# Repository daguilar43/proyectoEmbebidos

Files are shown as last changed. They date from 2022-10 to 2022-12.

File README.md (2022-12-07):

# Proyecto Sistemas Embebidos
#

Aquí pueden encontrarse todos los archivos del proyecto Amiplanta realizado para la materia Sistemas Embebidos durante el semestre 2022-2 en la Universidad Nacional de Colombia.
Dentro de estas carpetas pueden encontrarse:

*Proyecto en Kicad con el esquemático del dispositivo, huellas de los los diferentes componentes y layout de la PCB que fue enviada a producción con sus 
respectivas reglas de diseño + Logo del proyecto en la máscara de la PCB.

*Huellas realizadas manualmente de alunos componentes (utilizados para el diseño de la PCB).

*Código final desarrollado con ayuda de RIOT OS y el sdk para la Esp32-Wroom32, placa que fue utilizada para el montaje del proyecto.

*Modelo 3D utilizado para la matera.

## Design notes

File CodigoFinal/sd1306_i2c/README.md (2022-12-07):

#Código main.c

Este código utiliza las funciones de lectura y escritura definidas en los archivos de periféricos.
Además, se basa en el código ejemplo U8g2 para escribir y mostrar gráficos en una oled 128x64px.

Primero se realizar la inicialización de cada uno de los sensores. Posteriormente se realiza la inicialización de la pantalla.

Finalmente, se calculan las emociones a partir de medidas en cada uno de los sensores y se imprime en pantalla la emoción calculada.

Se cuenta con 5 emociones:

  *Feliz (todos los sensores en los rangos establecidos
  *Ahogado (demasiada humedad)
  *Sediento (humedad demasiado baja)
  *Oscuridad (baja luminosidad)
  *Frio (Temperatura baja)
  *Calor (Temperatura alta)

# U8g2 Package Test

## About
This is a test application for the U8g2 package. This package is a graphical display library, including display drivers.

## Usage
This test application will initialize the U8g2 to output on one of the following:

* output to terminal virtual screen.
* output to SDL virtual screen.
* output to I2C graphics screen.
* output to SPI graphics screen.

Note: you may have to run `make clean` after you changed to a different output mode.

### Output to terminal
To output to this virtual screen, supply `TEST_OUTPUT=1` to the `make` command.

### Output to SDL
To output to this virtual screen, supply `TEST_OUTPUT=2` to the `make` command.

This is a native-only option and requires SDL (32-bits) to be installed.

### Output to SPI
To output to screen, supply `TEST_OUTPUT=3` to the `make` command.

* `TEST_SPI` &mdash; The SPI device.
* `TEST_PIN_CS` &mdash; If applicable, the CS pin.
* `TEST_PIN_DC` &mdash; If applicable, the Data/Command pin.
* `TEST_PIN_RESET` &mdash; If applicable, the reset pin.
* `TEST_DISPLAY` &mdash; The used display driver (see https://github.com/olikraus/u8g2/wiki/u8g2setupc). Make sure you select a SPI compatible display.

### Output to I2C
To output to screen, supply `TEST_OUTPUT=4` to the `make` command.

Furthermore, you can configure the following:

* `TEST_I2C` &mdash; The I2C device.
* `TEST_ADDR` &mdash; The address to write commands to.
* `TEST_PIN_RESET` &mdash; If applicable, the reset pin.
* `TEST_DISPLAY` &mdash; The used display driver (see https://github.com/olikraus/u8g2/wiki/u8g2setupc). Make sure you select an I2C compatible display.

## Expected result
The output of this test depends on the output mode and used hardware. If it works, the application cycles through three screens with the text: 'This is RIOT-OS'.

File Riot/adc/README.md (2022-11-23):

ADC
===

Instrucciones de construcción
=============================

Acivar variables de entorno:

```bash
. environment.bash
```

Construir, flashear y monitorear:

```bash
    make b f t
```
Revisión de la documentación para modificaciones
================================================

https://doc.riot-os.org/group__drivers__periph__adc.html

ADC_NUMOF

/home/johnny/gitPackages/RIOT/boards/esp32-wroom-32/include/periph_conf.h
```bash
// ADC_GPIOS wroover
#define ADC_GPIOS   { GPIO0 , GPIO2 , GPIO4 , GPIO12, GPIO13, GPIO14, \
                      GPIO15, GPIO25, GPIO26, GPIO27, GPIO32, GPIO33, \
                      GPIO34, GPIO35, GPIO36, GPIO39 }
```

ADC_LINE(x)
Donde x es la posición que ocupa el pin en el arreglo de ADC_GPIOS

```bash
#define ADC_GPIOS {GPIO0, ..., GPIO39}
GPIO0 -> 0
GPIO2
GPIO4
GPIO12
GPIO13
GPIO14
GPIO15
GPIO25 -> 7
GPIO26
GPIO27
GPIO32
GPIO33
GPIO34
GPIO35
GPIO36
GPIO39 -> 15
```

/home/johnny/gitPackages/RIOT/boards/common/esp32/include/periph_conf_common.h

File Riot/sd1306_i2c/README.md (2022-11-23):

# U8g2 Package Test

## About
This is a test application for the U8g2 package. This package is a graphical display library, including display drivers.

## Usage
This test application will initialize the U8g2 to output on one of the following:

* output to terminal virtual screen.
* output to SDL virtual screen.
* output to I2C graphics screen.
* output to SPI graphics screen.

Note: you may have to run `make clean` after you changed to a different output mode.

### Output to terminal
To output to this virtual screen, supply `TEST_OUTPUT=1` to the `make` command.

### Output to SDL
To output to this virtual screen, supply `TEST_OUTPUT=2` to the `make` command.

This is a native-only option and requires SDL (32-bits) to be installed.

### Output to SPI
To output to screen, supply `TEST_OUTPUT=3` to the `make` command.

* `TEST_SPI` &mdash; The SPI device.
* `TEST_PIN_CS` &mdash; If applicable, the CS pin.
* `TEST_PIN_DC` &mdash; If applicable, the Data/Command pin.
* `TEST_PIN_RESET` &mdash; If applicable, the reset pin.
* `TEST_DISPLAY` &mdash; The used display driver (see https://github.com/olikraus/u8g2/wiki/u8g2setupc). Make sure you select a SPI compatible display.

### Output to I2C
To output to screen, supply `TEST_OUTPUT=4` to the `make` command.

Furthermore, you can configure the following:

* `TEST_I2C` &mdash; The I2C device.
* `TEST_ADDR` &mdash; The address to write commands to.
* `TEST_PIN_RESET` &mdash; If applicable, the reset pin.
* `TEST_DISPLAY` &mdash; The used display driver (see https://github.com/olikraus/u8g2/wiki/u8g2setupc). Make sure you select an I2C compatible display.

## Expected result
The output of this test depends on the output mode and used hardware. If it works, the application cycles through three screens with the text: 'This is RIOT-OS'.

##Imagen personalizada
Se debe preescalar la imagen deseada a 128*64px. Posteriormente utilizar la siguiente herramienta: https://javl.github.io/image2cpp/ para generar el mapa de bits en 128*64px

##Ruta del Riot
Modificar la variable RIOTBASE en archivo makefile y .envioroment para que corresponda con el directorio en el que se intaló RIOT.

##Ejecución

Ejecutar en consola:
*. environment.bash
*make all flash terminal

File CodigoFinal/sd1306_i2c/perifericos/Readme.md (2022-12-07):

Estos archivos contienen las funciones básicas para el funcionamiento de la Amiplanta.

El archivo adc.c contiene la lógica para la inicialización y lectura de cada uno de los sensores excepto el sensor de luz.
Estos sensores en general son adcs y gpios.

El archivo sensorLuz.c contiene la lógica para inicializar y controlar el sensor de luz utilizado. Este utiliza funciones base de i2c, lo que permite calibrar la 
resolución necesaria y prender el dispositivo para tomar lecturas.

El archivo carasOled.c contiene los mapas de bit de cada una de las emociones utilizadas por el programa. Además maneja la pantalla escribiendo los mapas de bits y 
calcula las emociones en funcion de la lectura de los diferentes sensores.

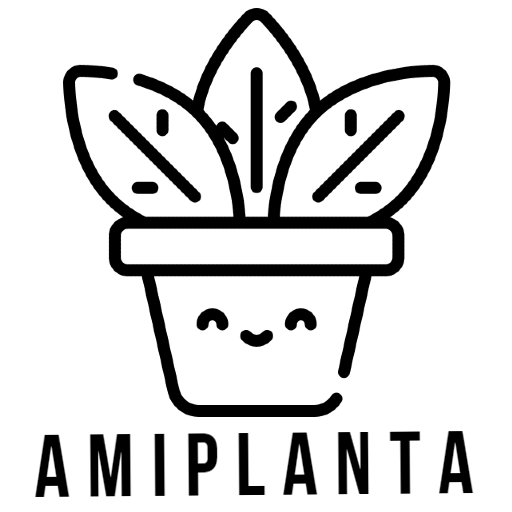
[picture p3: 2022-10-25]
Amiplanta.png

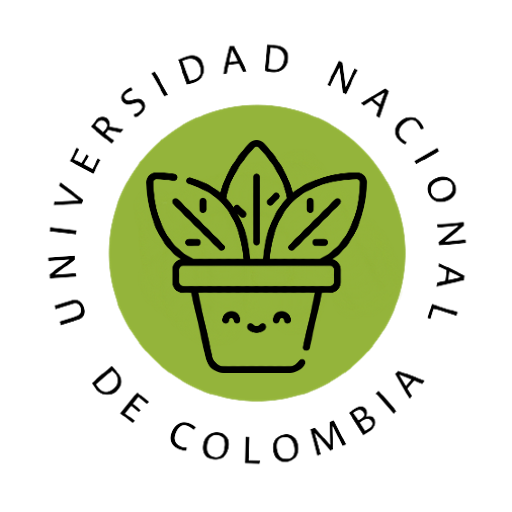
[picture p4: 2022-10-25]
EsquematicoV4/planta.png

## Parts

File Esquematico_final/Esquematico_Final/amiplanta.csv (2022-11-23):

Source: | /proyectoEmbebidos/proyectoEmbebidos/Esquematico_final/Esquematico_Final/amiplanta.kicad_sch
Date: | Tue 01 Nov 2022 10:18:04 AM -05
Tool: | Eeschema 6.0.9-8da3e8f707~116~ubuntu20.04.1
Generator: | /usr/share/kicad/plugins/bom_csv_grouped_by_value.py
Component Count: | 48
Individual Components:
Item | Qty | Reference(s) | Value | LibPart | Footprint | Datasheet | DESCRIPTION | MANUFACTURER | MAXIMUM_PACKAGE_HEIGHT | MP | PACKAGE | PARTREV | PRICE | STANDARD
 |  | Camp1 | 10u | Device:C | Capacitor_SMD:C_0805_2012Metric_Pad1.18x1.45mm_HandSolder | ~
 |  | Camp2 | 0.1u | Device:C | Capacitor_SMD:C_0805_2012Metric_Pad1.18x1.45mm_HandSolder | ~
 |  | Cbl1 | 0.1uF/50V(10%) | Device:C | Capacitor_SMD:C_0805_2012Metric_Pad1.18x1.45mm_HandSolder | ~
 |  | Cbl2 | 4.7uF/6.3V(10%) | Device:C | Capacitor_SMD:C_0805_2012Metric_Pad1.18x1.45mm_HandSolder | ~
 |  | Cboot1 | 0.1uF/50V(10%)(NC) | Device:C | Capacitor_SMD:C_0805_2012Metric_Pad1.18x1.45mm_HandSolder | ~
 |  | Cen2 | 0.1uF/50V(10%)(NC) | Device:C | Capacitor_SMD:C_0805_2012Metric_Pad1.18x1.45mm_HandSolder | ~
 |  | Cfeed1 | 22uF/10V(20%) | Device:C | Capacitor_SMD:C_0805_2012Metric_Pad1.18x1.45mm_HandSolder | ~
 |  | Cfeed2 | 0.1uF/50(10%) | Device:C | Capacitor_SMD:C_0805_2012Metric_Pad1.18x1.45mm_HandSolder | ~
 |  | CReg1 | 1u | Device:C | Capacitor_SMD:C_0805_2012Metric_Pad1.18x1.45mm_HandSolder | ~
 |  | CReg2 | 1u | Device:C | Capacitor_SMD:C_0805_2012Metric_Pad1.18x1.45mm_HandSolder | ~
 |  | Din1 | MBR1020VL | Diode:MBR1020VL | Diode_SMD:D_SOD-123F | https://www.onsemi.com/pub/Collateral/MBR1020VL-D.PDF
 |  | Dinl1 | LESD5D5.0CT1G | LESD5D5.0CT1G:LESD5D5.0CT1G | LESD5D5:TVS_LESD5D5.0CT1G |  |  | LRC | 0.7 mm |  |  | O |  | Manufacturer Recommendations
 |  | DUl1 | LESD5D5.0CT1G | LESD5D5.0CT1G:LESD5D5.0CT1G | LESD5D5:TVS_LESD5D5.0CT1G |  |  | LRC | 0.7 mm |  |  | O |  | Manufacturer Recommendations
 |  | DUl2 | LESD5D5.0CT1G | LESD5D5.0CT1G:LESD5D5.0CT1G | LESD5D5:TVS_LESD5D5.0CT1G |  |  | LRC | 0.7 mm |  |  | O |  | Manufacturer Recommendations
 |  | DUl3 | LESD5D5.0CT1G | LESD5D5.0CT1G:LESD5D5.0CT1G | LESD5D5:TVS_LESD5D5.0CT1G |  |  | LRC | 0.7 mm |  |  | O |  | Manufacturer Recommendations
 |  | DUSB1 | BAT760-7 | BAT760-7:BAT760-7 | SOD2513X120N |  |  | DIODES | 1.20mm |  |  | 9-2 |  | IPC-7351B
 |  | J1 | Jack-DC | Connector:Jack-DC | Connector_BarrelJack:BarrelJack_Horizontal | ~
 |  | J2 | USB_B_Micro | Connector:USB_B_Micro | Connector_USB:USB_Micro-B_Wuerth_629105150521 | ~
 |  | J3 | Conn_01x03_Female | Connector:Conn_01x03_Female | Connector_PinHeader_2.54mm:PinHeader_1x03_P2.54mm_Vertical | ~
 |  | Jhum1 | Conn_01x03_Female | Connector:Conn_01x03_Female | Connector_Molex:Molex_KK-396_A-41791-0003_1x03_P3.96mm_Vertical | ~
 |  | Jluc1 | Conn_01x06_Female | Connector:Conn_01x06_Female | Connector_Molex:Molex_KK-396_A-41791-0006_1x06_P3.96mm_Vertical | ~
 |  | Jmov1 | Conn_01x03_Female | Connector:Conn_01x03_Female | Connector_Molex:Molex_KK-396_A-41791-0003_1x03_P3.96mm_Vertical | ~
 |  | Joled1 | Conn_01x04_Female | Connector:Conn_01x04_Female | Connector_Molex:Molex_KK-396_5273-04A_1x04_P3.96mm_Vertical | ~
 |  | Jtem1 | Conn_01x03_Female | Connector:Conn_01x03_Female | Connector_Molex:Molex_KK-396_A-41791-0003_1x03_P3.96mm_Vertical | ~
 |  | Q1 | SS8050-G | SS8050-G:SS8050-G | SS8050-G:TRANS_SS8050-G |  |  | Comchip | 1.05 mm |  |  | A |  | Manufacturer Recommendations
 |  | Q2 | SS8050-G | SS8050-G:SS8050-G | SS8050-G:TRANS_SS8050-G |  |  | Comchip | 1.05 mm |  |  | A |  | Manufacturer Recommendations
 |  | R_rstbl1 | 2k(5%) | Device:R | Resistor_SMD:R_0805_2012Metric_Pad1.20x1.40mm_HandSolder | ~
 |  | Ractbl1 | 10k(5%) | Device:R | Resistor_SMD:R_0805_2012Metric_Pad1.20x1.40mm_HandSolder | ~
 |  | Rboot1 | 10K(5%) | Device:R | Resistor_SMD:R_0805_2012Metric_Pad1.20x1.40mm_HandSolder | ~
 |  | RDTR1 | 10K(5%) | Device:R | Resistor_SMD:R_0805_2012Metric_Pad1.20x1.40mm_HandSolder | ~
 |  | RED1 | LED | Device:LED | Resistor_SMD:R_0805_2012Metric_Pad1.20x1.40mm_HandSolder | ~
 |  | Ren1 | 10K(5%) | Device:R | Resistor_SMD:R_0805_2012Metric_Pad1.20x1.40mm_HandSolder | ~
 |  | Rpw1 | 1k | Device:R | Resistor_SMD:R_0805_2012Metric_Pad1.20x1.40mm_HandSolder | ~
 |  | RRTS1 | 10K(5%) | Device:R | Resistor_SMD:R_0805_2012Metric_Pad1.20x1.40mm_HandSolder | ~
 |  | RRXD0 | 0R(5%) | Device:R | Resistor_SMD:R_0805_2012Metric_Pad1.20x1.40mm_HandSolder | ~
 |  | rscl1 | 4.7k | Device:R | Resistor_SMD:R_0805_2012Metric_Pad1.20x1.40mm_HandSolder | ~
 |  | rsda1 | 4.7k | Device:R | Resistor_SMD:R_0805_2012Metric_Pad1.20x1.40mm_HandSolder | ~
 |  | Rtemp1 | 4,7k | Device:R | Resistor_SMD:R_0805_2012Metric_Pad1.20x1.40mm_HandSolder | ~
 |  | RTXD0 | 0R(5%) | Device:R | Resistor_SMD:R_0805_2012Metric_Pad1.20x1.40mm_HandSolder | ~
 |  | Rvbus1 | 22.1K(5%) | Device:R | Resistor_SMD:R_0805_2012Metric_Pad1.20x1.40mm_HandSolder | ~
 |  | Rvbus2 | 47.5K(5%) | Device:R | Resistor_SMD:R_0805_2012Metric_Pad1.20x1.40mm_HandSolder | ~
 |  | SWBoot1 | SW_Push | Switch:SW_Push | Button_Switch_SMD:SW_Push_1P1T_NO_6x6mm_H9.5mm | ~
 |  | SWEnable1 | SW_Push | Switch:SW_Push | Button_Switch_SMD:SW_Push_1P1T_NO_6x6mm_H9.5mm | ~
 |  | SWin1 | SW_DIP_x01 | Switch:SW_DIP_x01 | Button_Switch_SMD:SW_DIP_SPSTx01_Slide_9.78x4.72mm_W8.61mm_P2.54mm | ~
 |  | U2 | MAX98357AETE+ | MAX98357AETE_:MAX98357AETE+ | MAX9835_EditadoLib:MAX98357A_ModuloEditado | https://datasheets.maximintegrated.com/en/ds/MAX98357A-MAX98357B.pdf | Audio Amp Speaker 1-CH Mono Class-D 16-Pin TQFN EP | Maxim Integrated |  | MAX98357AETE+ | TQFN-16 Maxim Integrated |  | None | IPC7351B
 |  | U3 | ESP32-WROOM-32 | RF_Module:ESP32-WROOM-32 | RF_Module:ESP32-WROOM-32 | https://www.espressif.com/sites/default/files/documentation/esp32-wroom-32_datasheet_en.pdf
 |  | U7 | CP2102N-Axx-xQFN28 | Interface_USB:CP2102N-Axx-xQFN28 | Package_DFN_QFN:QFN-28-1EP_5x5mm_P0.5mm_EP3.35x3.35mm | https://www.silabs.com/documents/public/data-sheets/cp2102n-datasheet.pdf
 |  | UReg1 | AMS1117-3.3 | Regulator_Linear:AMS1117-3.3 | Package_TO_SOT_SMD:SOT-223-3_TabPin2 | http://www.advanced-monolithic.com/pdf/ds1117.pdf
Collated Components:
Item | Qty | Reference(s) | Value | LibPart | Footprint | Datasheet | DESCRIPTION | MANUFACTURER | MAXIMUM_PACKAGE_HEIGHT | MP | PACKAGE | PARTREV | PRICE | STANDARD
1 | 1 | Camp1 | 10u | Device:C | Capacitor_SMD:C_0805_2012Metric_Pad1.18x1.45mm_HandSolder | ~
2 | 1 | Camp2 | 0.1u | Device:C | Capacitor_SMD:C_0805_2012Metric_Pad1.18x1.45mm_HandSolder | ~
3 | 1 | Cbl1 | 0.1uF/50V(10%) | Device:C | Capacitor_SMD:C_0805_2012Metric_Pad1.18x1.45mm_HandSolder | ~
4 | 1 | Cbl2 | 4.7uF/6.3V(10%) | Device:C | Capacitor_SMD:C_0805_2012Metric_Pad1.18x1.45mm_HandSolder | ~
5 | 2 | Cboot1, Cen2 | 0.1uF/50V(10%)(NC) | Device:C | Capacitor_SMD:C_0805_2012Metric_Pad1.18x1.45mm_HandSolder | ~
6 | 1 | Cfeed1 | 22uF/10V(20%) | Device:C | Capacitor_SMD:C_0805_2012Metric_Pad1.18x1.45mm_HandSolder | ~
7 | 1 | Cfeed2 | 0.1uF/50(10%) | Device:C | Capacitor_SMD:C_0805_2012Metric_Pad1.18x1.45mm_HandSolder | ~
8 | 2 | CReg1, CReg2 | 1u | Device:C | Capacitor_SMD:C_0805_2012Metric_Pad1.18x1.45mm_HandSolder | ~
9 | 1 | Din1 | MBR1020VL | Diode:MBR1020VL | Diode_SMD:D_SOD-123F | https://www.onsemi.com/pub/Collateral/MBR1020VL-D.PDF
10 | 4 | Dinl1, DUl1, DUl2, DUl3 | LESD5D5.0CT1G | LESD5D5.0CT1G:LESD5D5.0CT1G | LESD5D5:TVS_LESD5D5.0CT1G |  |  | LRC | 0.7 mm |  |  | O |  | Manufacturer Recommendations
11 | 1 | DUSB1 | BAT760-7 | BAT760-7:BAT760-7 | SOD2513X120N |  |  | DIODES | 1.20mm |  |  | 9-2 |  | IPC-7351B
12 | 1 | J1 | Jack-DC | Connector:Jack-DC | Connector_BarrelJack:BarrelJack_Horizontal | ~
13 | 1 | J2 | USB_B_Micro | Connector:USB_B_Micro | Connector_USB:USB_Micro-B_Wuerth_629105150521 | ~
14 | 1 | J3 | Conn_01x03_Female | Connector:Conn_01x03_Female | Connector_PinHeader_2.54mm:PinHeader_1x03_P2.54mm_Vertical | ~
15 | 3 | Jhum1, Jmov1, Jtem1 | Conn_01x03_Female | Connector:Conn_01x03_Female | Connector_Molex:Molex_KK-396_A-41791-0003_1x03_P3.96mm_Vertical | ~
16 | 1 | Jluc1 | Conn_01x06_Female | Connector:Conn_01x06_Female | Connector_Molex:Molex_KK-396_A-41791-0006_1x06_P3.96mm_Vertical | ~
17 | 1 | Joled1 | Conn_01x04_Female | Connector:Conn_01x04_Female | Connector_Molex:Molex_KK-396_5273-04A_1x04_P3.96mm_Vertical | ~
18 | 2 | Q1, Q2 | SS8050-G | SS8050-G:SS8050-G | SS8050-G:TRANS_SS8050-G |  |  | Comchip | 1.05 mm |  |  | A |  | Manufacturer Recommendations
19 | 1 | R_rstbl1 | 2k(5%) | Device:R | Resistor_SMD:R_0805_2012Metric_Pad1.20x1.40mm_HandSolder | ~
20 | 1 | Ractbl1 | 10k(5%) | Device:R | Resistor_SMD:R_0805_2012Metric_Pad1.20x1.40mm_HandSolder | ~
21 | 4 | Rboot1, RDTR1, Ren1, RRTS1 | 10K(5%) | Device:R | Resistor_SMD:R_0805_2012Metric_Pad1.20x1.40mm_HandSolder | ~
22 | 1 | RED1 | LED | Device:LED | Resistor_SMD:R_0805_2012Metric_Pad1.20x1.40mm_HandSolder | ~
23 | 1 | Rpw1 | 1k | Device:R | Resistor_SMD:R_0805_2012Metric_Pad1.20x1.40mm_HandSolder | ~
24 | 2 | RRXD0, RTXD0 | 0R(5%) | Device:R | Resistor_SMD:R_0805_2012Metric_Pad1.20x1.40mm_HandSolder | ~
25 | 2 | rscl1, rsda1 | 4.7k | Device:R | Resistor_SMD:R_0805_2012Metric_Pad1.20x1.40mm_HandSolder | ~
26 | 1 | Rtemp1 | 4,7k | Device:R | Resistor_SMD:R_0805_2012Metric_Pad1.20x1.40mm_HandSolder | ~
27 | 1 | Rvbus1 | 22.1K(5%) | Device:R | Resistor_SMD:R_0805_2012Metric_Pad1.20x1.40mm_HandSolder | ~
28 | 1 | Rvbus2 | 47.5K(5%) | Device:R | Resistor_SMD:R_0805_2012Metric_Pad1.20x1.40mm_HandSolder | ~
29 | 2 | SWBoot1, SWEnable1 | SW_Push | Switch:SW_Push | Button_Switch_SMD:SW_Push_1P1T_NO_6x6mm_H9.5mm | ~
30 | 1 | SWin1 | SW_DIP_x01 | Switch:SW_DIP_x01 | Button_Switch_SMD:SW_DIP_SPSTx01_Slide_9.78x4.72mm_W8.61mm_P2.54mm | ~
31 | 1 | U2 | MAX98357AETE+ | MAX98357AETE_:MAX98357AETE+ | MAX9835_EditadoLib:MAX98357A_ModuloEditado | https://datasheets.maximintegrated.com/en/ds/MAX98357A-MAX98357B.pdf | Audio Amp Speaker 1-CH Mono Class-D 16-Pin TQFN EP | Maxim Integrated |  | MAX98357AETE+ | TQFN-16 Maxim Integrated |  | None | IPC7351B
32 | 1 | U3 | ESP32-WROOM-32 | RF_Module:ESP32-WROOM-32 | RF_Module:ESP32-WROOM-32 | https://www.espressif.com/sites/default/files/documentation/esp32-wroom-32_datasheet_en.pdf
33 | 1 | U7 | CP2102N-Axx-xQFN28 | Interface_USB:CP2102N-Axx-xQFN28 | Package_DFN_QFN:QFN-28-1EP_5x5mm_P0.5mm_EP3.35x3.35mm | https://www.silabs.com/documents/public/data-sheets/cp2102n-datasheet.pdf
34 | 1 | UReg1 | AMS1117-3.3 | Regulator_Linear:AMS1117-3.3 | Package_TO_SOT_SMD:SOT-223-3_TabPin2 | http://www.advanced-monolithic.com/pdf/ds1117.pdf

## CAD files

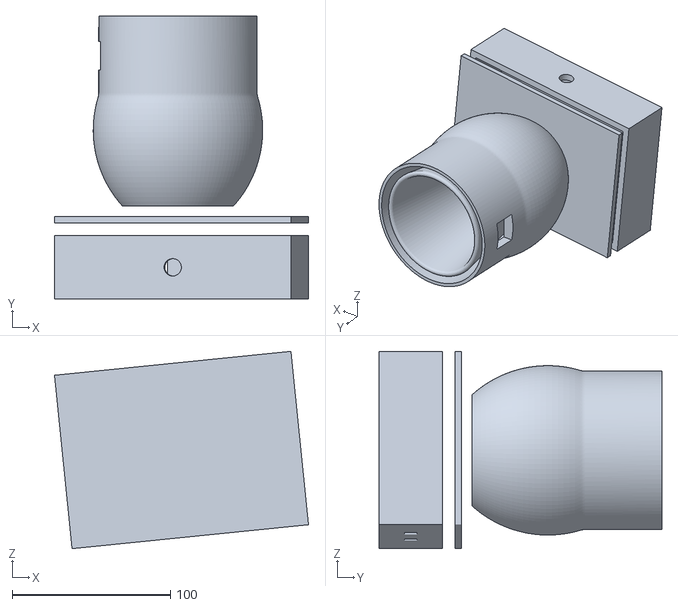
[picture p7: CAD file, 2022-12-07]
ensamble v11.stl
160.3 x 178.6 x 124.6

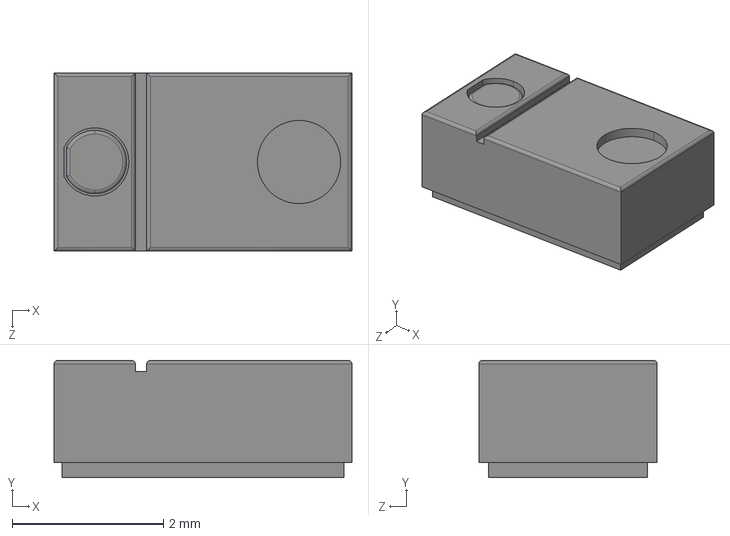
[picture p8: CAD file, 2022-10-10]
Esquematico_final/Esquematico_Final/Componentes/APDS-9960/APDS-9960.step
3.94 x 1.55 x 2.36 mm

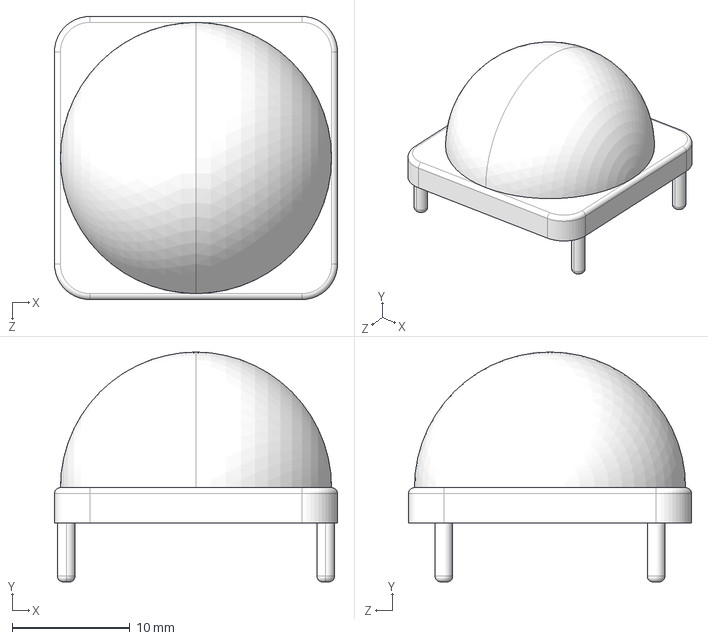
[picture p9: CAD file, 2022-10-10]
Esquematico_final/Esquematico_Final/Componentes/HC-SR501/HC-SR501-master/lens.STEP
24.0 x 19.5 x 24.0 mm

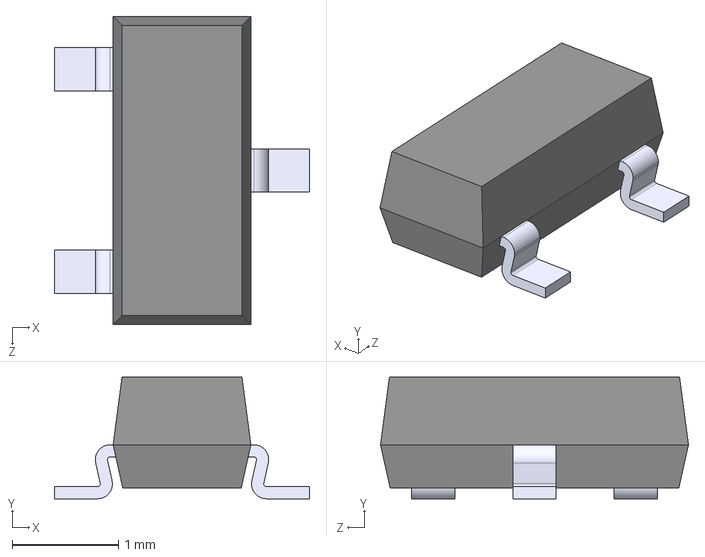
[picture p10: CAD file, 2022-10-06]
Esquematico_final/Esquematico_Final/Componentes/SS8050-G/SS8050-G.step
2.40 x 1.14 x 2.90 mm

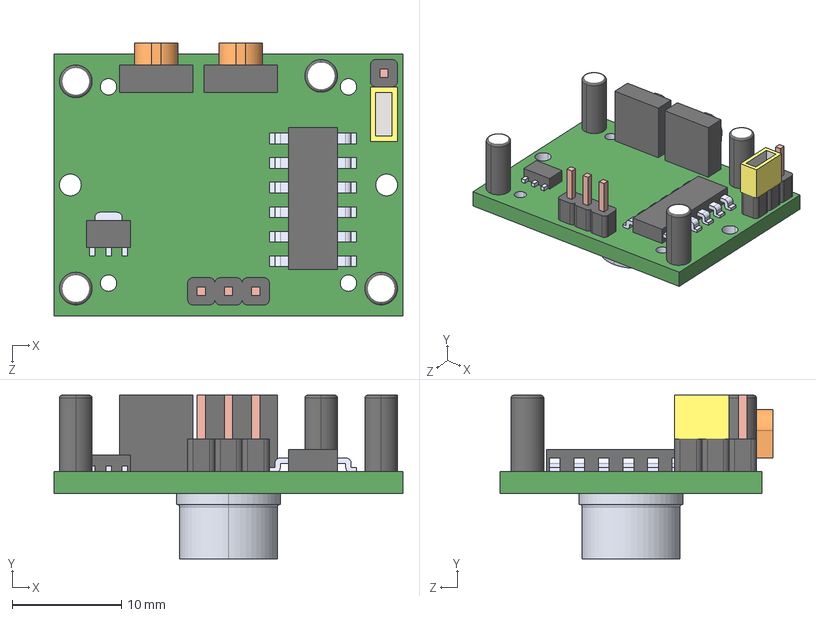
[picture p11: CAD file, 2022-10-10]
Esquematico_final/Esquematico_Final/Componentes/HC-SR501/HC-SR501-master/sensor.STEP
32.0 x 15.0 x 25.0 mm

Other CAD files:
Esquematico_final/Esquematico_Final/Componentes/HC-SR501/HC-SR501-master/sensor board.STEP
Esquematico_final/Esquematico_Final/Componentes/HC-SR501/HC-SR501-master/lens.SLDPRT
Esquematico_final/Esquematico_Final/Componentes/HC-SR501/HC-SR501-master/sensor.SLDASM
Esquematico_final/Esquematico_Final/Componentes/HC-SR501/HC-SR501-master/sensor.SLDPRT

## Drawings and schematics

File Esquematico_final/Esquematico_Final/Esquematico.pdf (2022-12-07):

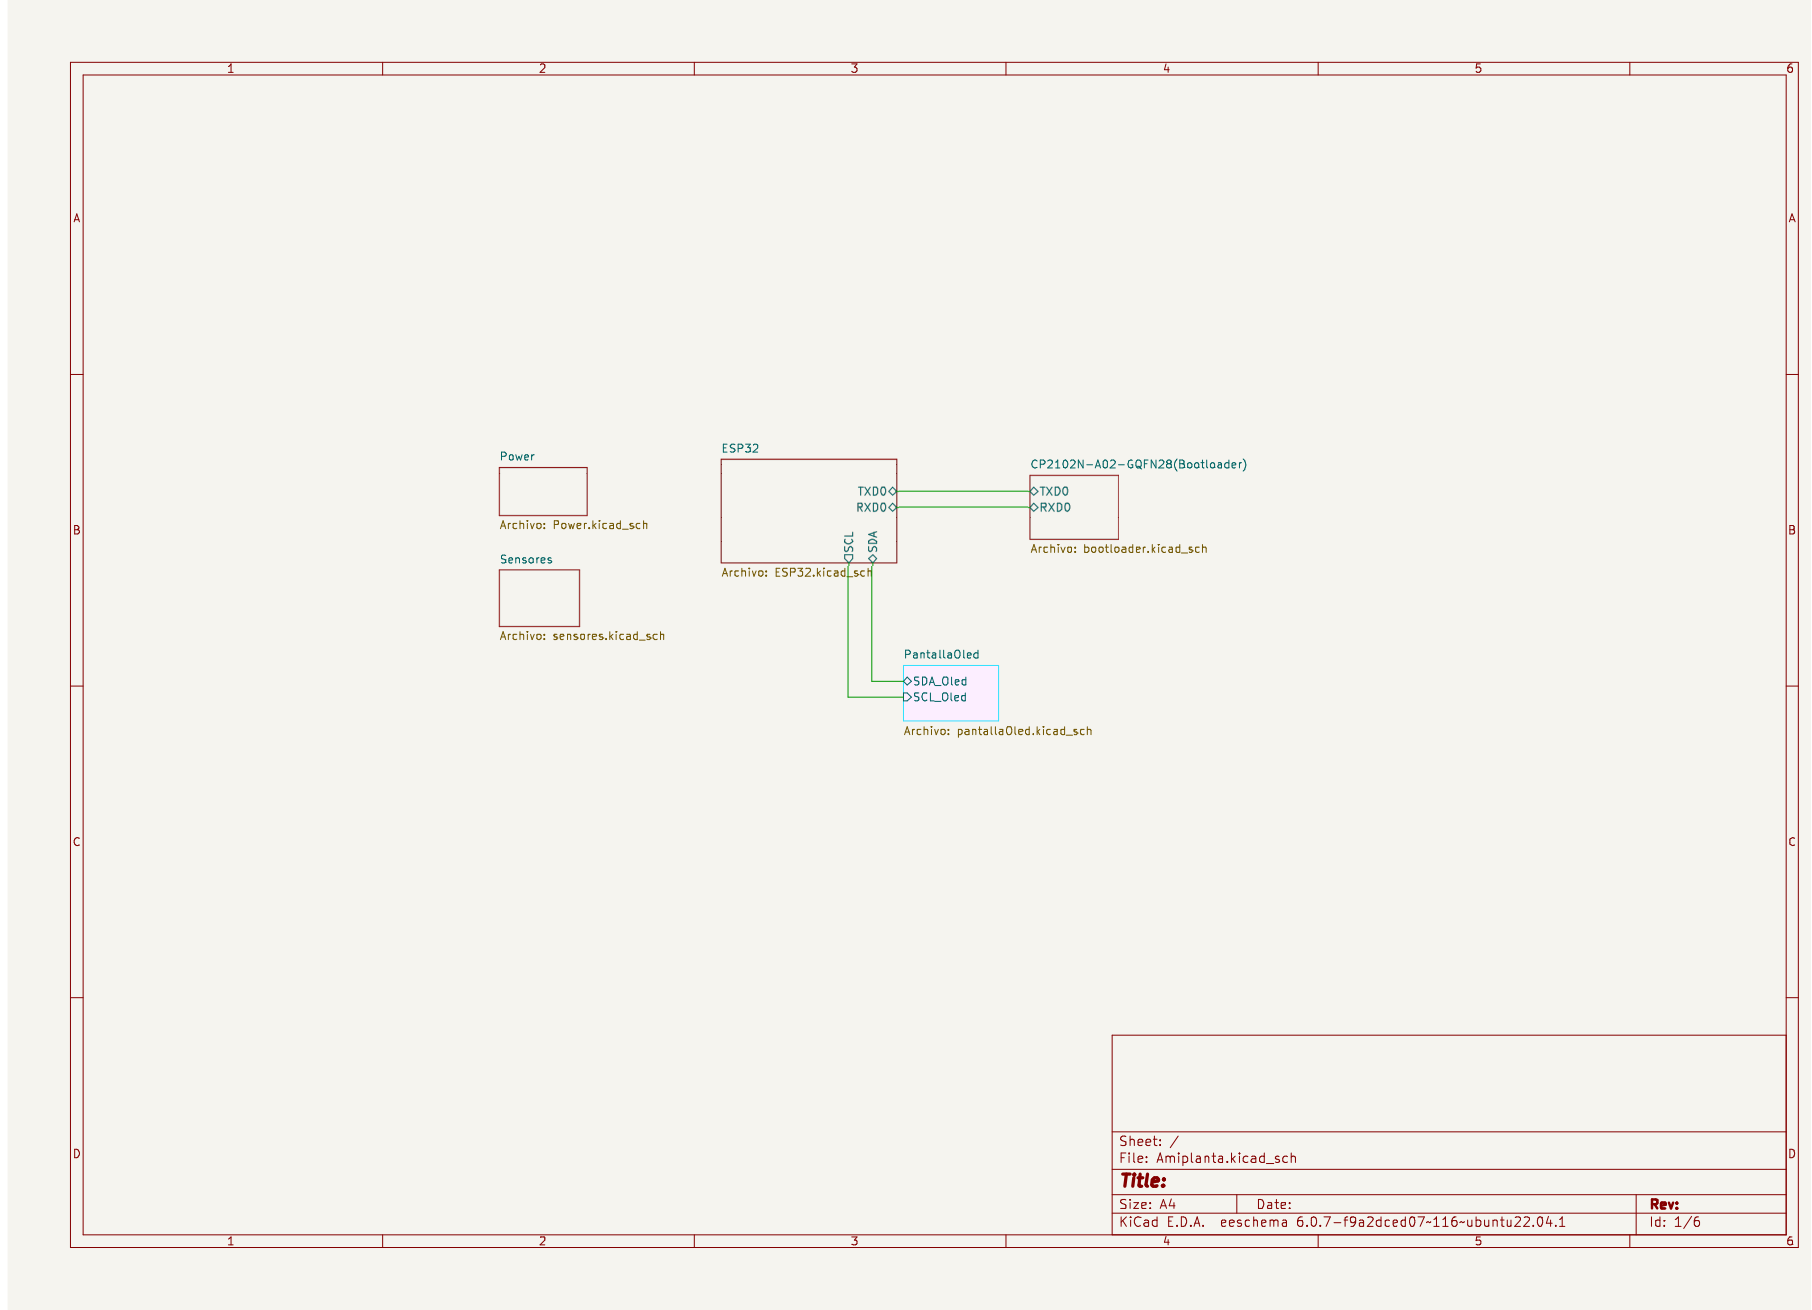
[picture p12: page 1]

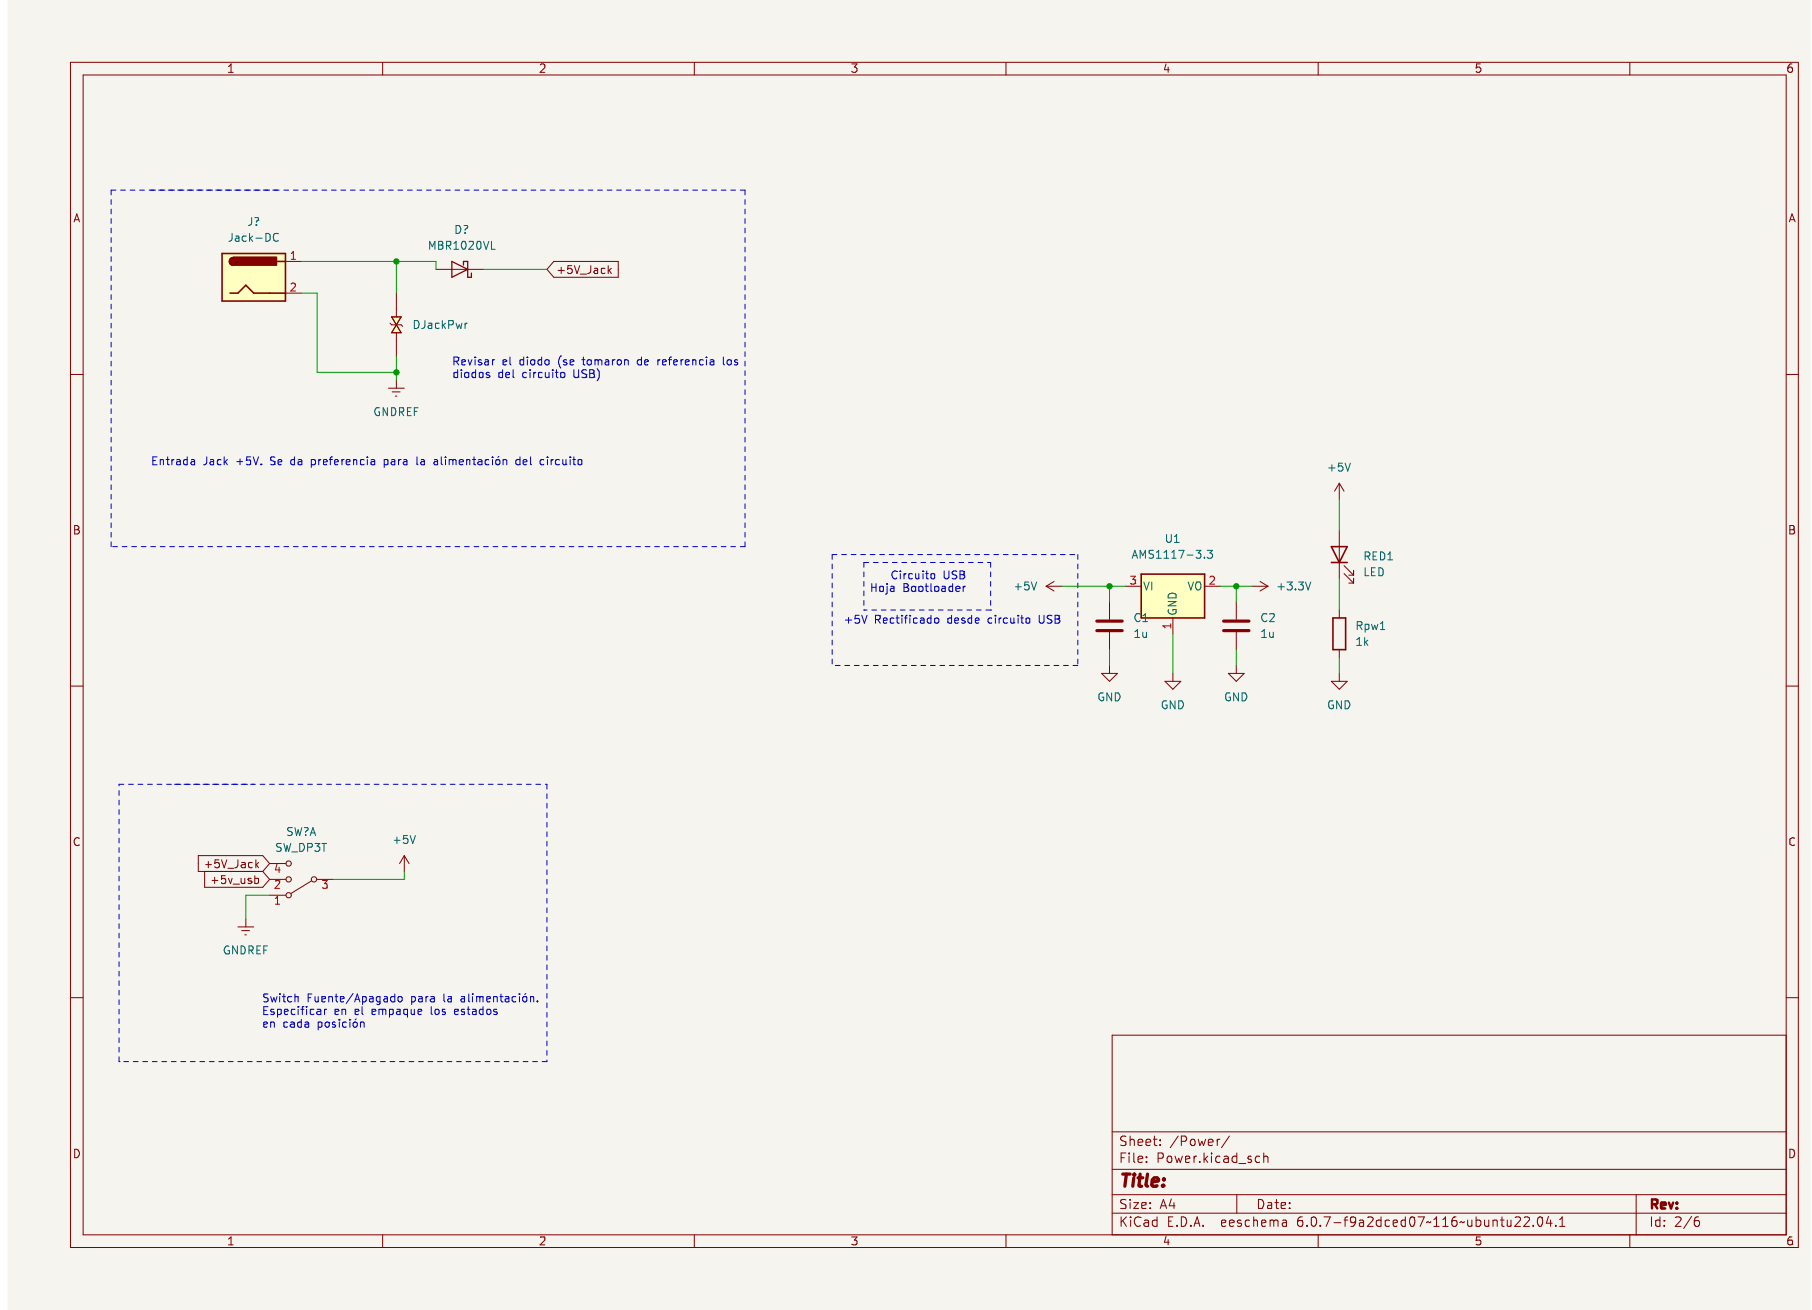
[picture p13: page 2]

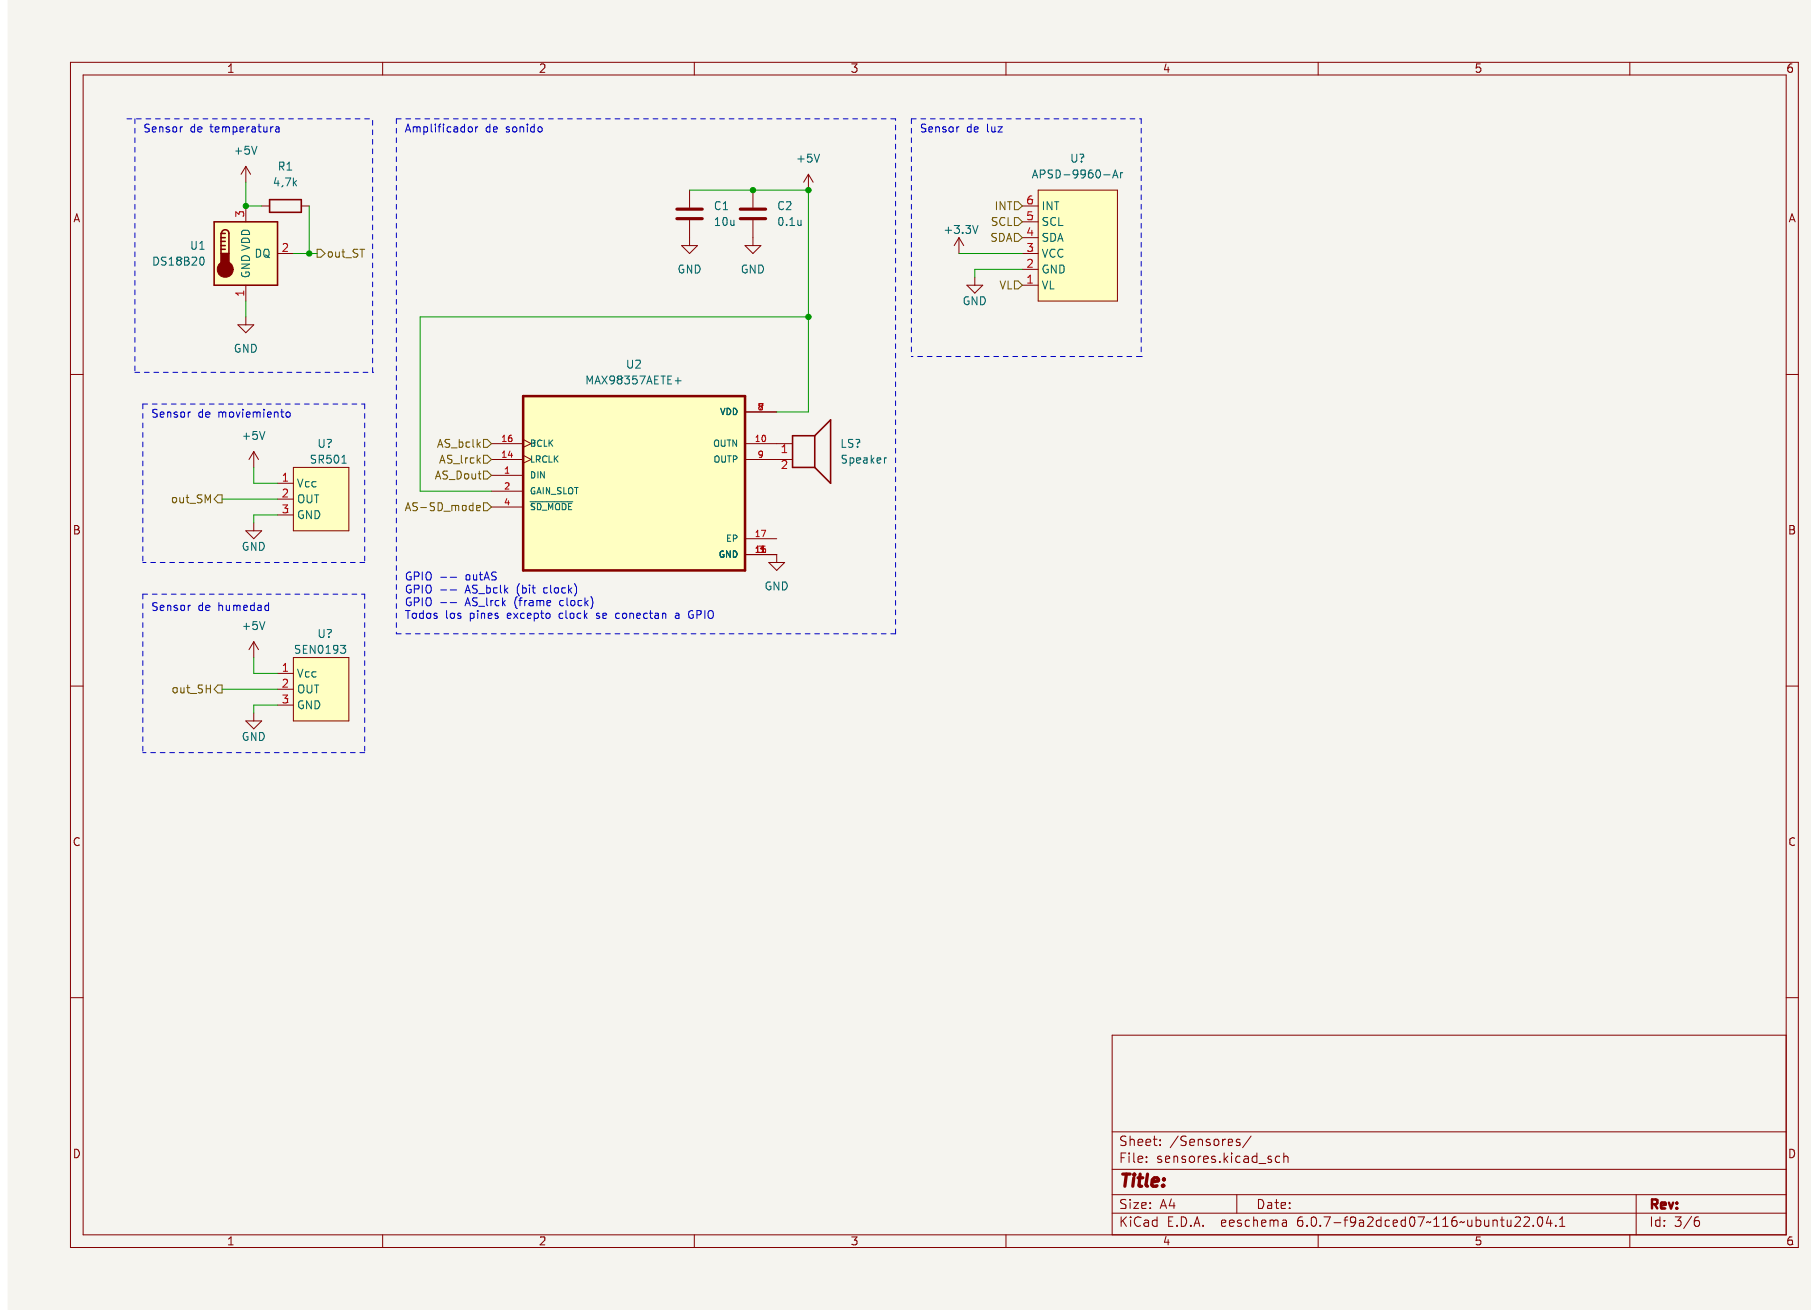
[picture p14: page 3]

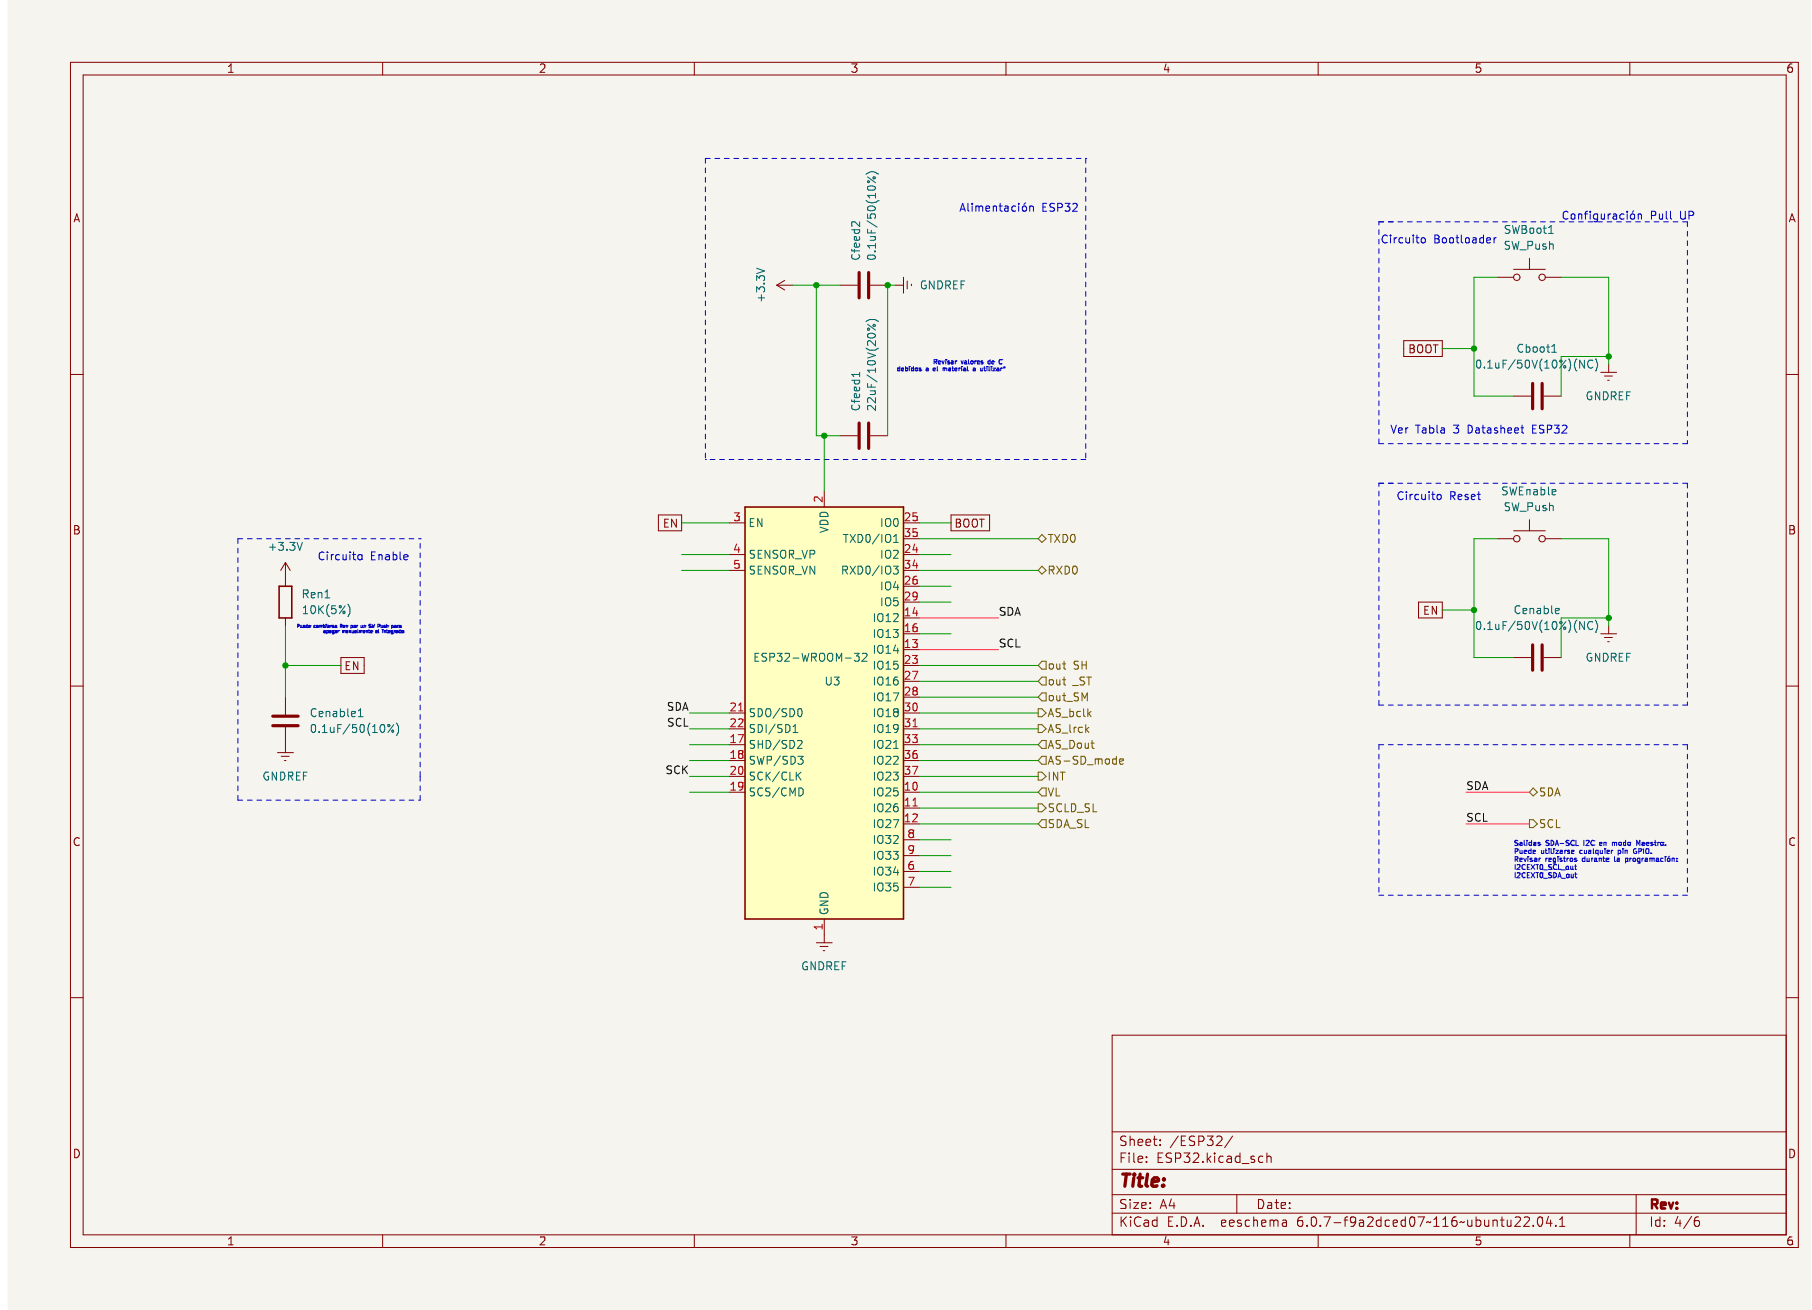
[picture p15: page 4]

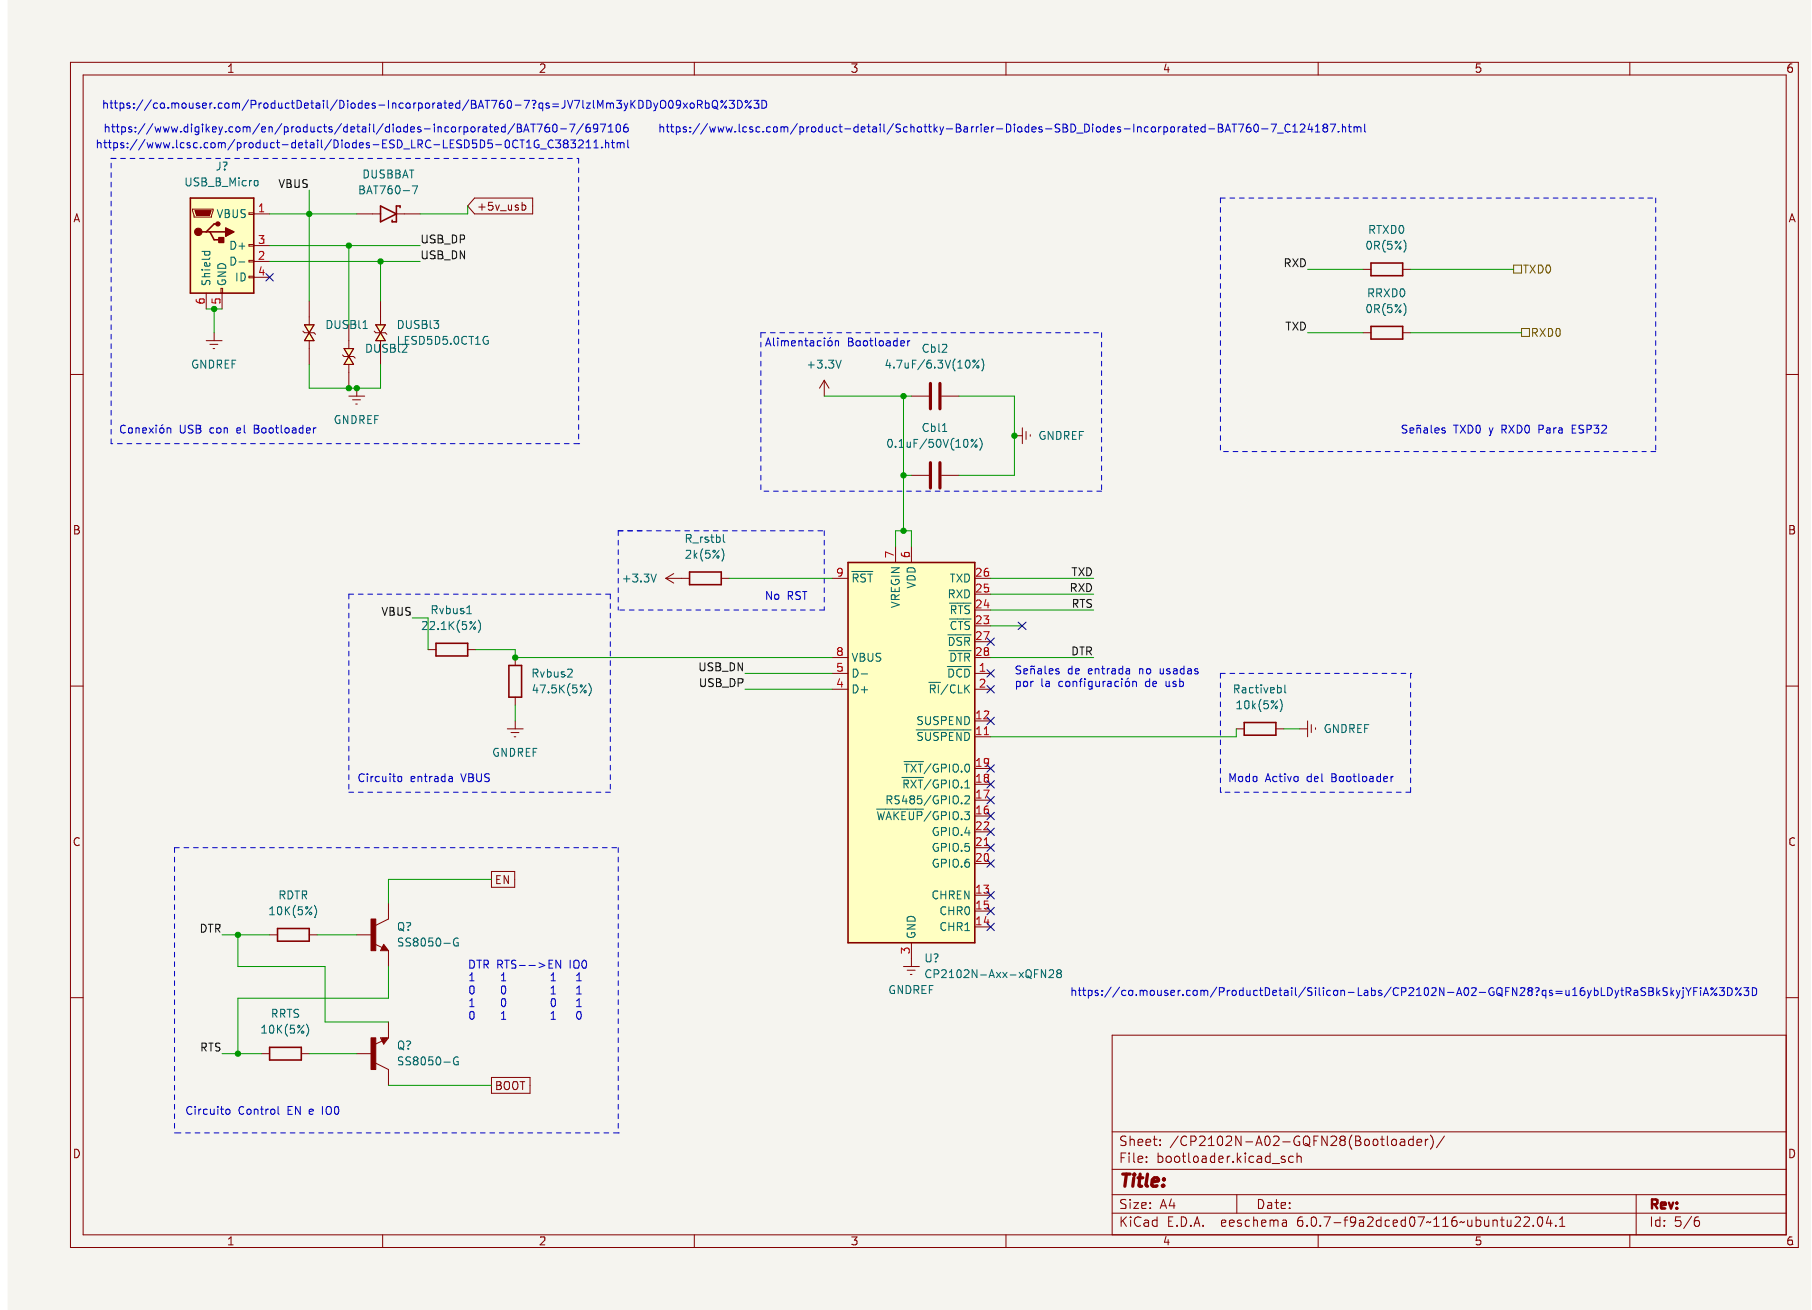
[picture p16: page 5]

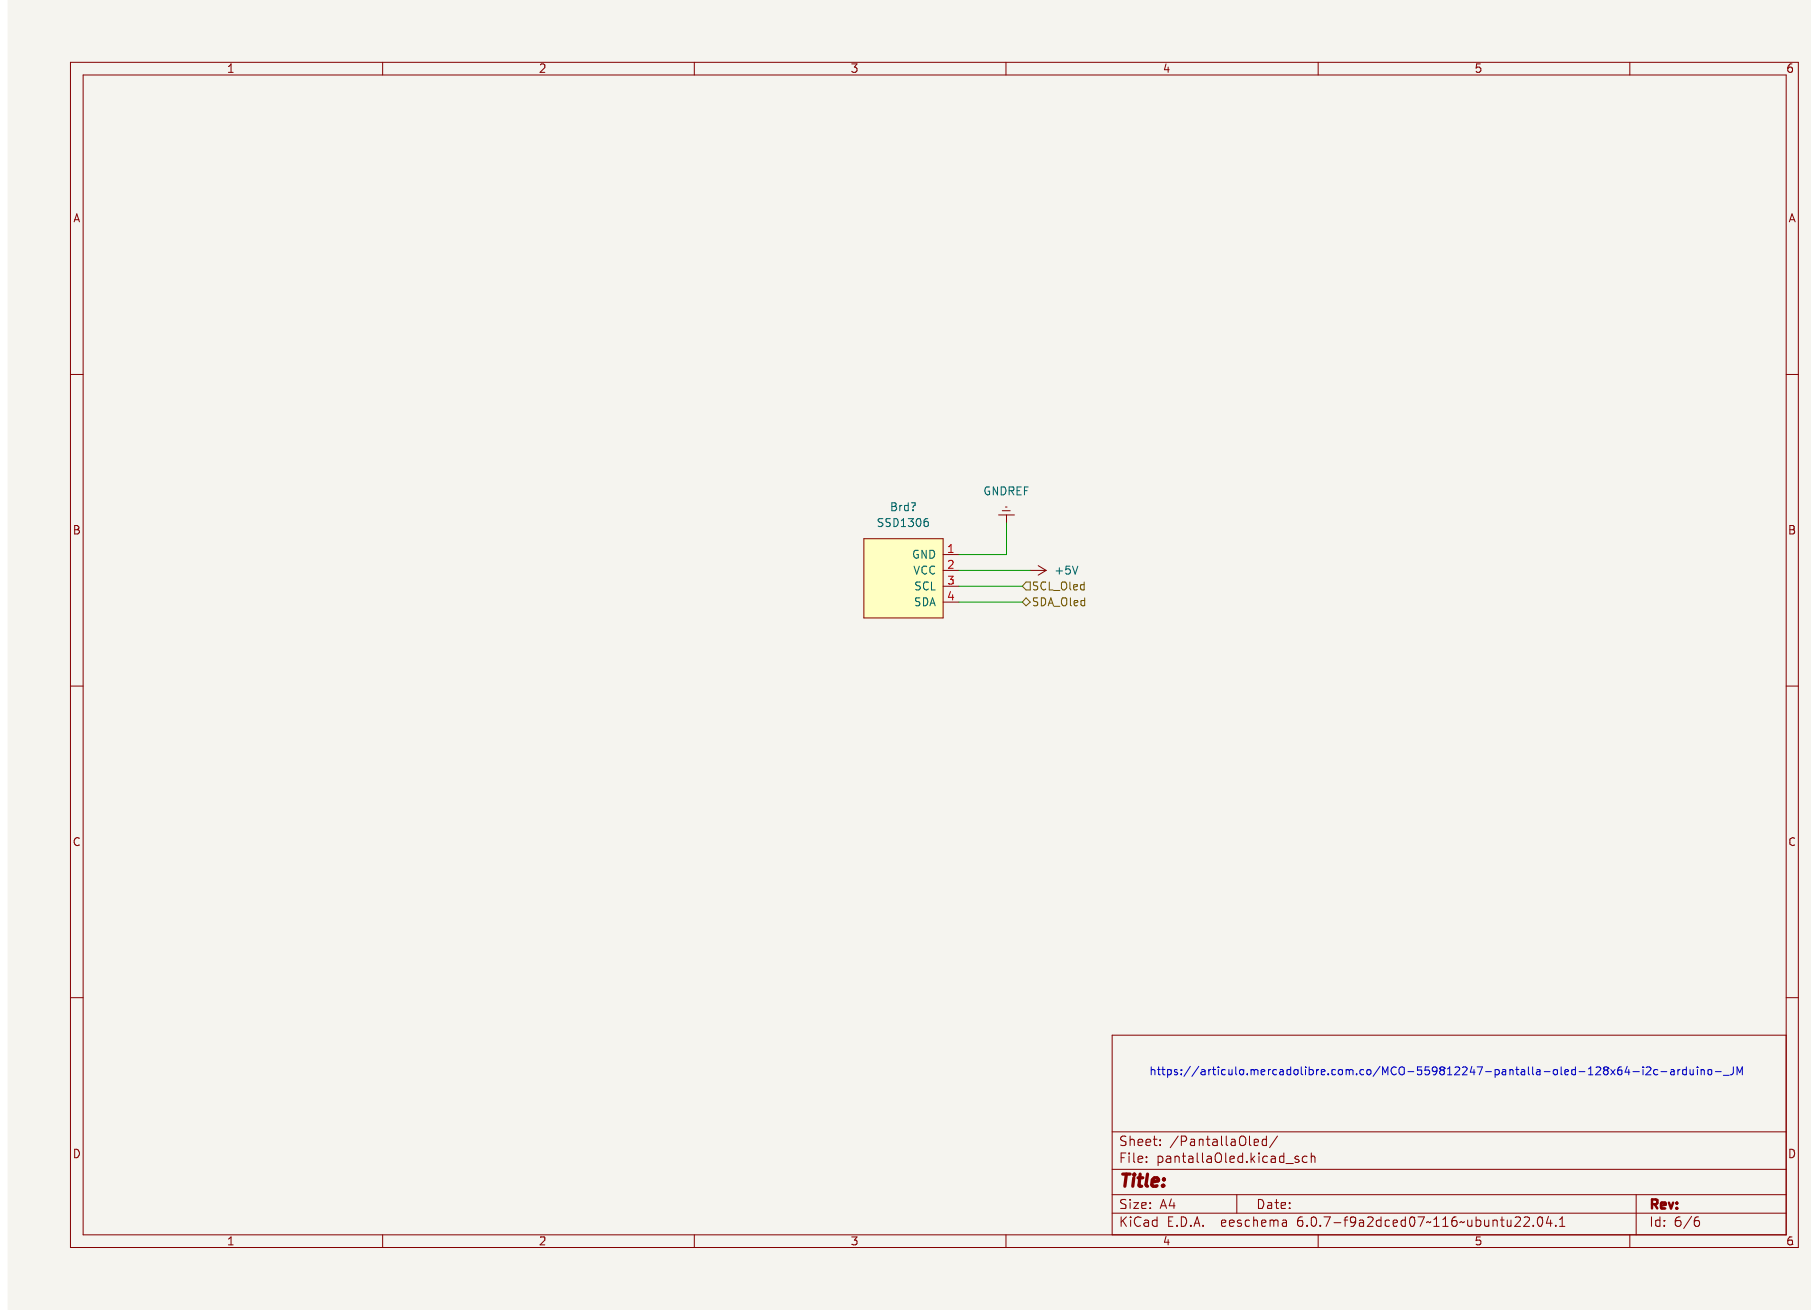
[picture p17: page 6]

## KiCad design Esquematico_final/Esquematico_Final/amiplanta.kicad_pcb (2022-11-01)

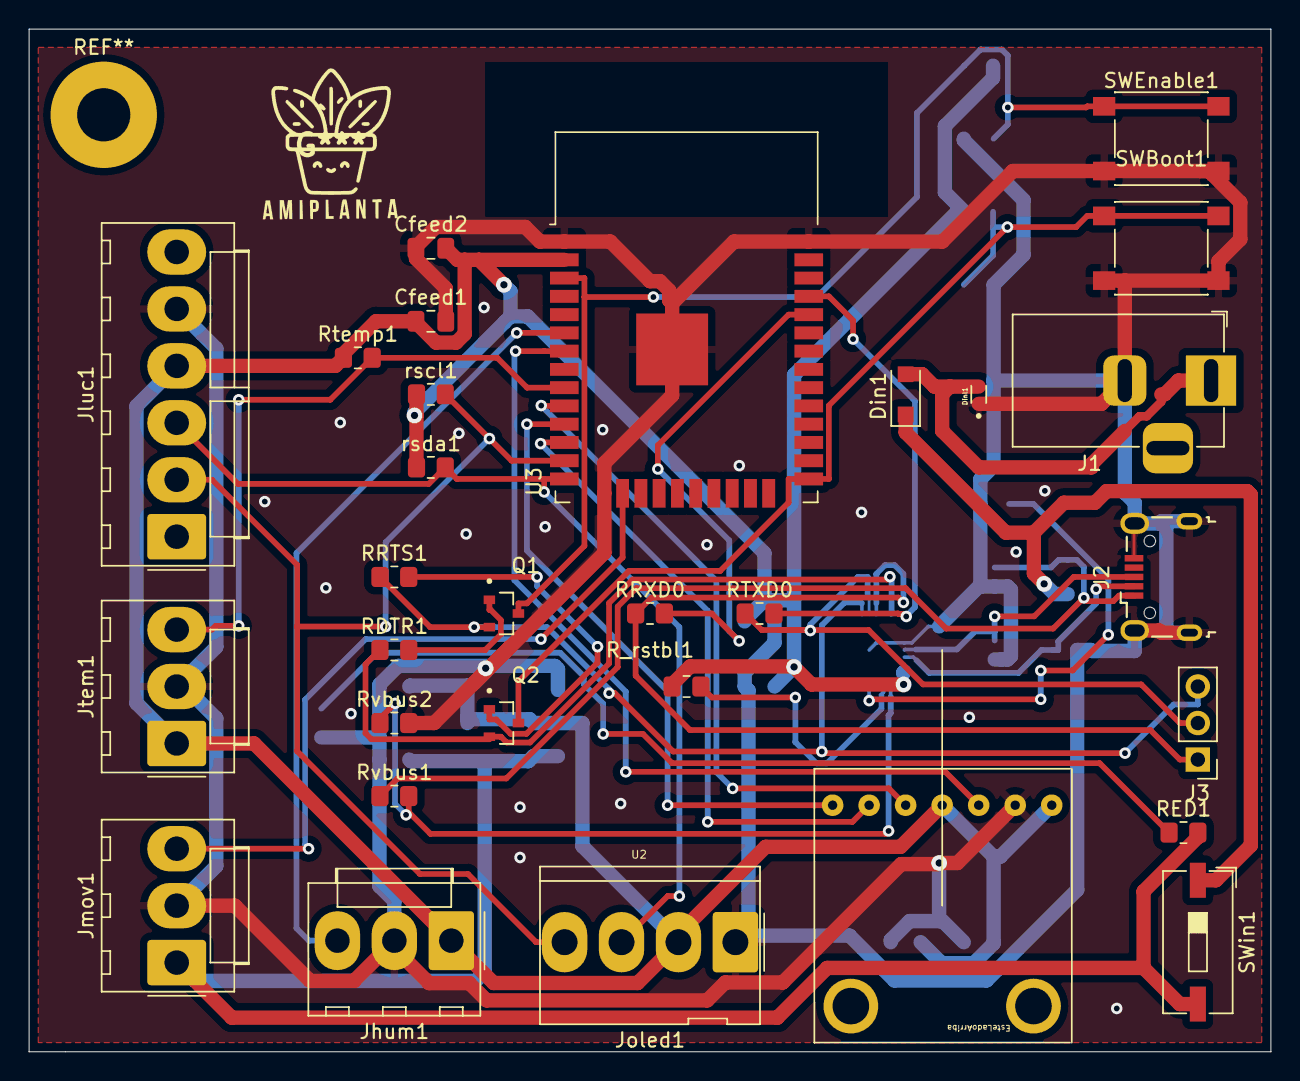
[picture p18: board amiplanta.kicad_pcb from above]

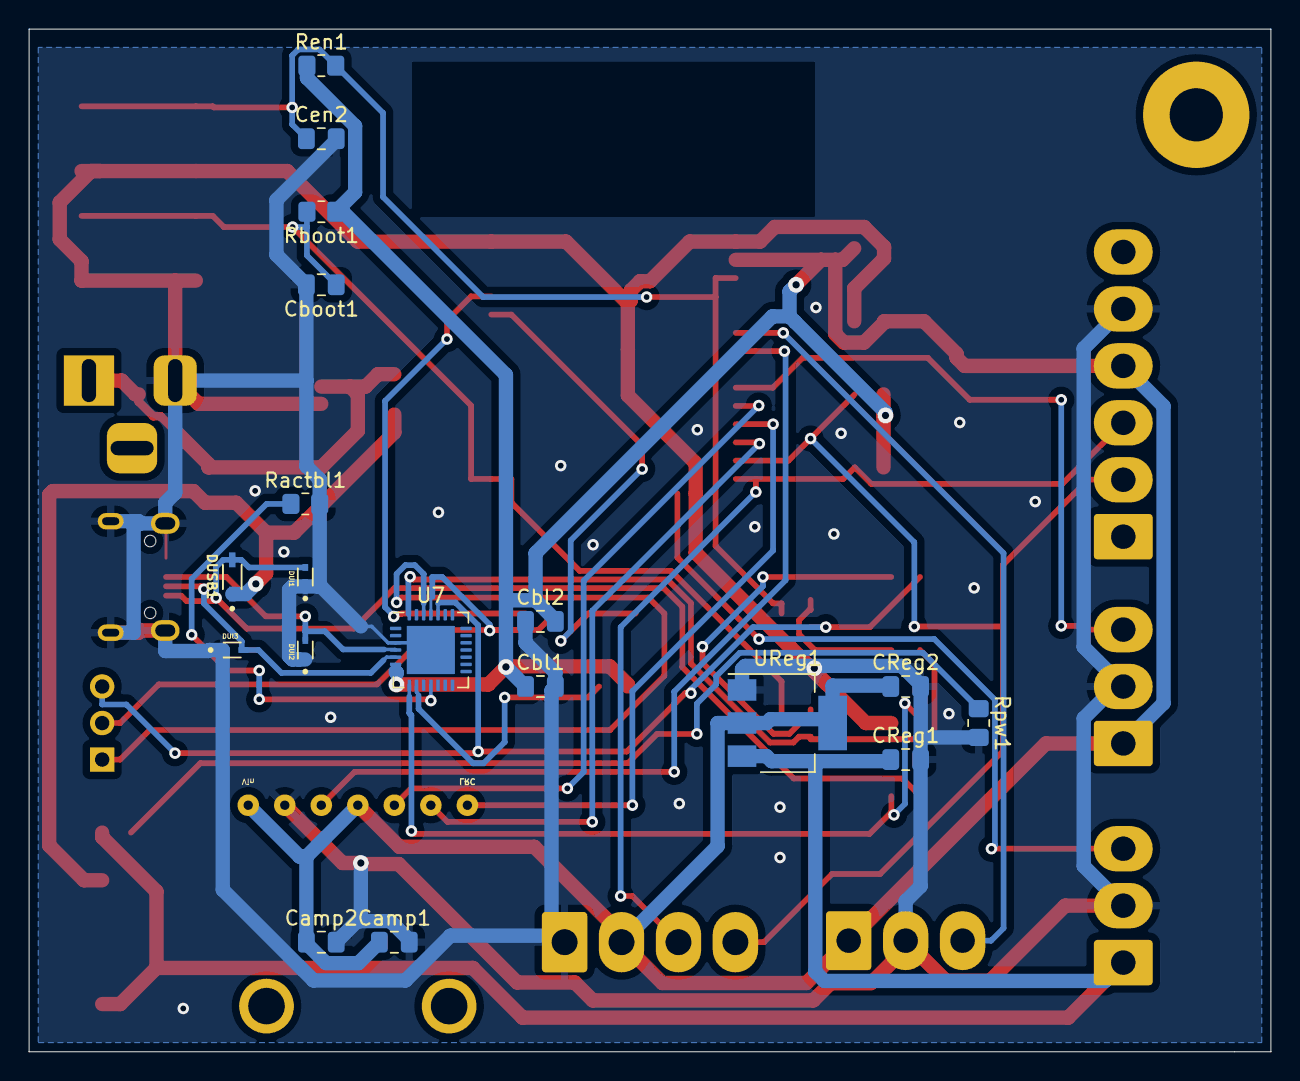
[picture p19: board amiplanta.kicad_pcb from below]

Board: 2 copper layers, 86.4 x 71.1 mm, 48 parts (18 on the bottom side), 31 nets.

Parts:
CReg1, CReg2: 1u; C_0805_2012Metric_Pad1.18x1.45mm_HandSolder
Camp1: 10u; C_0805_2012Metric_Pad1.18x1.45mm_HandSolder
Camp2: 0.1u; C_0805_2012Metric_Pad1.18x1.45mm_HandSolder
Cbl1: 0.1uF/50V(10%); C_0805_2012Metric_Pad1.18x1.45mm_HandSolder
Cbl2: 4.7uF/6.3V(10%); C_0805_2012Metric_Pad1.18x1.45mm_HandSolder
Cboot1: 0.1uF/50V(10%)(NC); C_0805_2012Metric_Pad1.18x1.45mm_HandSolder
Cen2: 0.1uF/50V(10%)(NC); C_0805_2012Metric_Pad1.18x1.45mm_HandSolder
Cfeed1: 22uF/10V(20%); C_0805_2012Metric_Pad1.18x1.45mm_HandSolder
Cfeed2: 0.1uF/50(10%); C_0805_2012Metric_Pad1.18x1.45mm_HandSolder
DUSB1: BAT760-7; SOD2513X120N
DUl1, DUl2, DUl3: LESD5D5.0CT1G; TVS_LESD5D5.0CT1G
Din1: MBR1020VL; D_SOD-123F
Dinl1: LESD5D5.0CT1G; TVS_LESD5D5.0CT1G
J1: Jack-DC; BarrelJack_Horizontal
J2: USB_B_Micro; USB_Micro-B_Wuerth_629105150521
J3: Conn_01x03_Female; PinHeader_1x03_P2.54mm_Vertical
Jhum1: Conn_01x03_Female; Molex_KK-396_A-41791-0003_1x03_P3.96mm_Vertical
Jluc1: Conn_01x06_Female; Molex_KK-396_A-41791-0006_1x06_P3.96mm_Vertical
Jmov1: Conn_01x03_Female; Molex_KK-396_A-41791-0003_1x03_P3.96mm_Vertical
Joled1: Conn_01x04_Female; Molex_KK-396_5273-04A_1x04_P3.96mm_Vertical
Jtem1: Conn_01x03_Female; Molex_KK-396_A-41791-0003_1x03_P3.96mm_Vertical
Q1, Q2: SS8050-G; TRANS_SS8050-G
RDTR1: 10K(5%); R_0805_2012Metric_Pad1.20x1.40mm_HandSolder
RED1: LED; R_0805_2012Metric_Pad1.20x1.40mm_HandSolder
RRTS1: 10K(5%); R_0805_2012Metric_Pad1.20x1.40mm_HandSolder
RRXD0: 0R(5%); R_0805_2012Metric_Pad1.20x1.40mm_HandSolder
RTXD0: 0R(5%); R_0805_2012Metric_Pad1.20x1.40mm_HandSolder
R_rstbl1: 2k(5%); R_0805_2012Metric_Pad1.20x1.40mm_HandSolder
Ractbl1: 10k(5%); R_0805_2012Metric_Pad1.20x1.40mm_HandSolder
Rboot1: 10K(5%); R_0805_2012Metric_Pad1.20x1.40mm_HandSolder
Ren1: 10K(5%); R_0805_2012Metric_Pad1.20x1.40mm_HandSolder
Rpw1: 1k; R_0805_2012Metric_Pad1.20x1.40mm_HandSolder
Rtemp1: 4,7k; R_0805_2012Metric_Pad1.20x1.40mm_HandSolder
Rvbus1: 22.1K(5%); R_0805_2012Metric_Pad1.20x1.40mm_HandSolder
Rvbus2: 47.5K(5%); R_0805_2012Metric_Pad1.20x1.40mm_HandSolder
SWBoot1: SW_Push; SW_Push_1P1T_NO_6x6mm_H9.5mm
SWEnable1: SW_Push; SW_Push_1P1T_NO_6x6mm_H9.5mm
SWin1: SW_DIP_x01; SW_DIP_SPSTx01_Slide_9.78x4.72mm_W8.61mm_P2.54mm
U2: MAX98357AETE+; MAX98357A_ModuloEditado
U3: ESP32-WROOM-32
U7: CP2102N-Axx-xQFN28; QFN-28-1EP_5x5mm_P0.5mm_EP3.35x3.35mm
UReg1: AMS1117-3.3; SOT-223-3_TabPin2
rscl1: 4.7k; R_0805_2012Metric_Pad1.20x1.40mm_HandSolder
rsda1: 4.7k; R_0805_2012Metric_Pad1.20x1.40mm_HandSolder

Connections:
+3.3V: CReg2.1, Camp1.1, Camp2.1, Cbl1.1, Cbl2.2, Cfeed1.1, Cfeed2.2, Jhum1.1, Jluc1.4, Joled1.2, Jtem1.1, R_rstbl1.1, Rboot1.1, Ren1.1, Rtemp1.1, U2.1 (VDD), U2.4 (GAIN_SLOT), U3.2 (VDD), U7.6 (VDD), U7.7 (VREGIN), UReg1.2 (VO), rscl1.1, rsda1.1
+5V: CReg1.1, Jmov1.1, RED1.2 (A), SWin1.2, UReg1.3 (VI)
+5V_Jack: DUSB1.C, Din1.1 (K), SWin1.1
/CP2102N-A02-GQFN28(Bootloader)/DTR: Q2.2, RDTR1.1, U7.28 (~DTR)
/CP2102N-A02-GQFN28(Bootloader)/RTS: J3.3, Q1.2, RRTS1.1, U7.24 (~RTS)
/CP2102N-A02-GQFN28(Bootloader)/RXD: J3.2, RTXD0.1, U7.25 (RXD)
/CP2102N-A02-GQFN28(Bootloader)/RXD0: RRXD0.2, U3.34 (RXD0/IO3)
/CP2102N-A02-GQFN28(Bootloader)/TXD: J3.1, RRXD0.1, U7.26 (TXD)
/CP2102N-A02-GQFN28(Bootloader)/TXD0: RTXD0.2, U3.35 (TXD0/IO1)
/CP2102N-A02-GQFN28(Bootloader)/USB_DN: DUl3.2, J2.2 (D-), U7.5 (D-)
/CP2102N-A02-GQFN28(Bootloader)/USB_DP: DUl2.2, J2.3 (D+), U7.4 (D+)
/CP2102N-A02-GQFN28(Bootloader)/VBUS: DUSB1.A, DUl1.2, J2.1 (VBUS), Rvbus1.1
/ESP32/Amp_Din: U2.5 (DIN), U3.10 (IO25)
/ESP32/BCLK: U2.6 (BCLK), U3.12 (IO27)
/ESP32/LRC: U2.7 (LRCLK), U3.11 (IO26)
/ESP32/SCL: Jluc1.2, Joled1.4, U3.13 (IO14), rscl1.2
/ESP32/SDA: Jluc1.3, Joled1.3, U3.14 (IO12), rsda1.2
/ESP32/amp_D_mode: U2.3 (~SD_MODE), U3.7 (IO35)
/Sensores/dh: Jhum1.3, U3.6 (IO34)
/Sensores/dm: Jmov1.3, U3.16 (IO13)
/Sensores/dt: Jtem1.3, Rtemp1.2, U3.9 (IO33)
BOOT: Cboot1.1, Q2.3, Rboot1.2, SWBoot1.1, U3.25 (IO0)
EN: Cen2.1, Q1.3, Ren1.2, SWEnable1.1, U3.3 (EN)
GNDREF: CReg1.2, CReg2.2, Camp1.2, Camp2.2, Cbl1.2, Cbl2.1, Cboot1.2, Cen2.2, Cfeed1.2, Cfeed2.1, DUl1.1, DUl2.1, DUl3.1, Dinl1.1, J1.2, J2.5 (GND), J2.6 (Shield), Jhum1.2, Jluc1.5, Jmov1.2, Joled1.1, Jtem1.2, Ractbl1.2, Rpw1.2, Rvbus2.2, SWBoot1.2, SWEnable1.2, U2.2 (GND), U3.1 (GND), U3.15 (GND), U3.38 (GND), U3.39 (GND), U7.3 (GND), U7.29 (GND), UReg1.1 (GND)
unnamed: Din1.2 (A), Dinl1.2, J1.1
unnamed: Q1.1, RDTR1.2
unnamed: Q2.1, RRTS1.2
unnamed: RED1.1 (K), Rpw1.1
unnamed: R_rstbl1.2, U7.9 (~RST)
unnamed: Ractbl1.1, U7.11 (~SUSPEND)
unnamed: Rvbus1.2, Rvbus2.1, U7.8 (VBUS)

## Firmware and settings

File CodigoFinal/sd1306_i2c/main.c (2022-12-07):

/*
 * Copyright (C) 2016 Bas Stottelaar <basstottelaar@gmail.com>
 *
 * This file is subject to the terms and conditions of the GNU Lesser
 * General Public License v2.1. See the file LICENSE in the top level
 * directory for more details.
 */

/**
 * @ingroup     tests
 * @{
 *
 * @file
 * @brief       Test application for the U8g2 package.
 *
 * @author      Bas Stottelaar <basstottelaar@gmail.com>
 *
 * @}
 */
#ifndef INDEX_DRIVER_HW_I2C
#error "INDEX_DRIVER_HW_I2C not defined"
#endif

#ifndef TEST_ADDR
#error "TEST_ADDR not defined"
#endif

#ifndef SETUP_DISPLAY
#error "SETUP_DISPLAY not defined"
#endif

#ifndef TEST_PIN_RESET
#error "TEST_PIN_RESET not defined"
#endif

#include <stdio.h>

#include "periph/gpio.h"
#include "periph/i2c.h"

#include "timex.h"
#include "ztimer.h"

#include "u8g2.h"
#include "u8x8_riotos.h"




#include "periph/gpio.h"
#include "periph/i2c.h"
#include "periph/adc.h"

#include "timex.h"
#include "ztimer.h"

#include "u8g2.h"
#include "u8x8_riotos.h"


#include "perifericos/carasPantalla.c"


//sensores digitales
#define movimiento GPIO4
//Indicadores digitales
#define LED0_PIN GPIO25

#define RES             ADC_RES_10BIT
#define DELAY_MS        100000U



#define gpioMovimiento GPIO13

const int gpioTemp =10;
const int gpioHumedad =11;
const int gpioMovimientoInt=1;

bool movst=false;
bool onoff=true;




int main(void)
{
     int emocion=0;
    initSensorLuz();
  //  escribirPantalla(0,readSensorLuz());
    init_adc(gpioTemp);
    init_adc(gpioHumedad);
    gpio_init(gpioMovimiento, GPIO_IN);
    pantallaInit(gpioTemp);


    while (1) {
      movst=gpio_read(gpioMovimiento);
      onoff=cronometroMovimiento(movst);


    escribirPantalla(emocion,onoff);
      if(onoff){
  

    emocion=determinarEmocion(readSensorLuz(),read_adc(gpioTemp),read_adc(gpioHumedad));

    ztimer_sleep(ZTIMER_USEC, US_PER_SEC);
      }

    }

    return 0;
}

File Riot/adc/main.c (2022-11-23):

/*
 * Copyright (C) 2014-2015 Freie Universität Berlin
 *
 * This file is subject to the terms and conditions of the GNU Lesser
 * General Public License v2.1. See the file LICENSE in the top level
 * directory for more details.
 */

/**
 * @ingroup     tests
 * @{
 *
 * @file
 * @brief       Test application for peripheral ADC drivers
 *
 * @author      Hauke Petersen <hauke.petersen@fu-berlin.de>
 *
 * @}
 */

#include <stdio.h>
#include "timex.h"
#include "ztimer.h"
#include "periph/adc.h"
#include "periph/i2c.h"
#include "u8g2.h"
#include "u8x8_riotos.h"

 
#define SSD1306_I2C_ADDR    (61)
    
// Codigo tomado de controlador para arduino 

//i2c_t oled_dev;
//

//u8g2_t u8g2;

//u8x8_riotos_t user_data =
//{
  //  .device_index = 0,
    //.pin_sda = GPIO_PIN(PA, 22),
    //.pin_scl = GPIO_PIN(PA, 23)
//};
 
 //u8g2_SetUserPtr(&u8g2, &user_data);
 //u8g2_Setup_ssd1306_128x64_noname_1(&u8g2, U8G2_R0, u8x8_byte_riotos_hw_i2c, u8x8_gpio_and_delay_riotos);



#define RES             ADC_RES_10BIT
#define DELAY_MS        1000U



// Funcion de Inicializacion tomada de https://github.com/HendrikVE/RIOT/commit/82b88cb98eaeb9043f8a1635f10317d687ce3f43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
void esp_i2c_init(i2c_t dev) {

  //  assert(dev);
  //  assert(params);

  //  dev->params = *params;

    i2c_init(0);

    //uint8_t _functionSet = 0;

    // configure bit mode
    //if (params->bit_mode == BITMODE_8_BIT) {
    //    _functionSet |= (1 << BIT_FUNCTION_SET_BITMODE);
   // }

    // configure line count
    //if (params->row_count >= 2) {
    //    _functionSet |= (1 << BIT_FUNCTION_SET_LINECOUNT);
   // }

    // configure character size
    //if (params->font_size == FONT_SIZE_5x10) {
     //   _functionSet |= (1 << BIT_FUNCTION_SET_FONTSIZE);
   // }

    // SEE PAGE 45/46 FOR INITIALIZATION SPECIFICATION!
    // according to datasheet, we need at least 40ms after power rises above 2.7V
    // before sending commands. Arduino can turn on way before 4.5V so we'll wait 50 ms
   // xtimer_usleep(50 * US_PER_MS);

    // this is according to the hitachi HD44780 datasheet
    // page 45 figure 23

    // Send function set command sequence
   // _command(dev, CMD_FUNCTION_SET | _functionSet);
   // xtimer_usleep(5 * US_PER_MS);

    // second try
    //_command(dev, CMD_FUNCTION_SET | _functionSet);
    //xtimer_usleep(500);

    // third go
  //  _command(dev, CMD_FUNCTION_SET | _functionSet);

    // above three calls to _command will return -ENXIO, but subsequent calls
    // should give no error

  //**  hd44780_i2c_turn_on(dev);
   // hd44780_i2c_clear(dev);
    //hd44780_i2c_set_text_insertion_mode(dev, LEFT_TO_RIGHT);

   // return ESP_OK;
}



/* static const uint8_t logo[] = {
    0x00, 0x00, 0x00, 0x00, 0x00, 0x00, 0x00, 0x00, 0x00, 0x00, 0x03, 0xE0,
    0x00, 0x00, 0x00, 0x00, 0x00, 0x00, 0x0F, 0xF8, 0x00, 0x00, 0x00, 0x00,
    0x00, 0x00, 0x1F, 0xF8, 0x00, 0x00, 0x00, 0x00, 0x00, 0x00, 0x3E, 0x3C,
    0x00, 0x00, 0x00, 0x00, 0x00, 0x00, 0x78, 0x1E, 0x00, 0x00, 0x00, 0x00,
    0x00, 0x00, 0x70, 0x0E, 0x00, 0x00, 0x00, 0x00, 0x00, 0x00, 0x70, 0x0E,
    0x00, 0x00, 0x00, 0x00, 0x00, 0x00, 0xF0, 0x0E, 0x00, 0x00, 0x00, 0x00,
    0x00, 0x00, 0xF0, 0x0E, 0x00, 0x00, 0x00, 0x00, 0x00, 0x00, 0xF0, 0x1E,
    0x00, 0x00, 0x00, 0x00, 0x00, 0x00, 0xF0, 0x3C, 0x00, 0x00, 0x00, 0x00,
    0x00, 0x00, 0xF0, 0x7C, 0x00, 0x00, 0x00, 0x00, 0x00, 0x00, 0x73, 0xF8,
    0x30, 0x3C, 0x3F, 0xC0, 0x00, 0x0C, 0x77, 0xF0, 0x38, 0x7E, 0x3F, 0xC0,
    0x00, 0x7E, 0x73, 0xC0, 0x38, 0xE7, 0x06, 0x00, 0x00, 0xFC, 0x71, 0x00,
    0x38, 0xE3, 0x06, 0x00, 0x01, 0xF0, 0x70, 0x00, 0x38, 0xE3, 0x06, 0x00,
    0x01, 0xC0, 0x70, 0x00, 0x38, 0xE3, 0x06, 0x00, 0x03, 0x80, 0x70, 0xC0,
    0x38, 0xE3, 0x06, 0x00, 0x03, 0x80, 0x71, 0xE0, 0x38, 0xE3, 0x06, 0x00,
    0x03, 0x80, 0x70, 0xE0, 0x38, 0xE3, 0x06, 0x00, 0x03, 0x80, 0x70, 0xF0,
    0x38, 0xE3, 0x06, 0x00, 0x03, 0x80, 0x70, 0x70, 0x38, 0xE3, 0x06, 0x00,
    0x03, 0x80, 0xF0, 0x78, 0x38, 0xE3, 0x06, 0x00, 0x03, 0xC1, 0xE0, 0x3C,
    0x38, 0xE7, 0x06, 0x00, 0x01, 0xE3, 0xE0, 0x3C, 0x38, 0x7E, 0x06, 0x00,
    0x01, 0xFF, 0xC0, 0x1C, 0x30, 0x3C, 0x06, 0x00, 0x00, 0x7F, 0x80, 0x00,
    0x00, 0x00, 0x00, 0x00, 0x00, 0x1C, 0x00, 0x00, 0x00, 0x00, 0x00, 0x00,
    0x00, 0x00, 0x00, 0x00, 0x00, 0x00, 0x00, 0x00, 0x00, 0x00, 0x00, 0x00,
    0x00, 0x00, 0x00, 0x00
}; */







int main(void)
{

ztimer_sleep(ZTIMER_MSEC, DELAY_MS);


 i2c_init(0);



///Inicializacion i2C
//esp_i2c_init(oled_dev);

//i2c_acquire(0);
///

  // int sample = 0;

    //puts("\nRIOT ADC peripheral driver test\n");
    //puts("This test will sample all available ADC lines once every 100ms with\n"
      //   "a 10-bit resolution and print the sampled results to STDIO\n\n");

    /* initialize all available ADC lines */
    /* for (unsigned i = 0; i < ADC_NUMOF; i++) { */
    /*     if (adc_init(ADC_LINE(i)) < 0) { */
    /*         printf("Initialization of ADC_LINE(%u) failed\n", i); */
    /*         return 1; */
    /*     } else { */
    /*         printf("Successfully initialized ADC_LINE(%u)\n", i); */
    /*     } */
    /* } */

    /* initialize all available ADC lines */
    //if(adc_init(ADC_LINE(7)) < 0){
      //  return 1;
    //}

   // adc_init(ADC_LINE(7));



 // i2c_init(0);
uint16_t add_Oled=61 ;//"01111000"
uint8_t  contrByte=0x80  ;// Para comandos
uint8_t  contrBytedata=0x40  ;// Para escribir datos
//uint8_t  dataByte=175;
uint8_t linea1=230;
uint8_t rutinaInicio[]={contrByte, 0xA8,  0x3F,  0xD3, 0x00,  0x40, 0xA0,  0xC0,  0xDA, 
 02, 0x81, 0xA4, 0xA6,  0xD5, 0x80, 0x8D, 0x14,  0xAF,0xA5, contrBytedata, linea1};
//uint8_t todoON=0xA5;
// first, acquire the shared bus again
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

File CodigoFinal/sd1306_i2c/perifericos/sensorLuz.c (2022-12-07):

#include <stdio.h>
#include <stdlib.h>
#include <errno.h>

#include "periph_conf.h"
#include "periph/gpio.h"
#include "periph/i2c.h"
#include "shell.h"

#include <xtimer.h>

#ifndef I2C_ACK
#define I2C_ACK         (0)
#endif

uint8_t data;




int initSensorLuz(void){
i2c_acquire(0);
if(i2c_write_reg(0, 0x39,0x80,3,0)==0){
puts("0x39 0x80 3 0 existoso");
}
if(i2c_write_reg(0, 0x39,0x8F,2,0)==0){
puts("0x39 0x8F 2 0 exitoso");
}
if(i2c_read_reg(0, 0x39,0x94,&data,0)==0 ){

    puts("Read Operation Succesful");
}
printf("Valor incial %02x",data);
i2c_release(0);

return 1;
}

int readSensorLuz(void){
i2c_acquire(0);
if(i2c_read_reg(0, 0x39,0x94,&data,0)==0 ){

    puts("Read Operation Succesful");
}
printf("%02x",data);
i2c_release(0);
return data;
}

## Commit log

2022-09-27 Add files via upload
    Primer avance esquematico
    [Amiplanta.kicad_sch, ESP32.kicad_sch, Esquematico.kicad_pcb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]
2022-10-06 Esquemáticos tentativos de Bootloader, Conexión USB y Potencia. Revisar valores de los componentes, especialmente Capacitores
    [Amiplanta.kicad_sch, ESP32.kicad_sch, Esquematico.kicad_pcb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]
2022-10-06 Esquematicos sin error en texto plano
    [Amiplanta.kicad_sch, ESP32.kicad_sch, Power.kicad_sch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]
2022-10-06 intento push
    [Amiplanta.kicad_sch, ESP32.kicad_sch, bootloader.kicad_sch]
2022-10-06 Circuito Pantalla Oled SSD1306 implementado. Modelo y Footprints SD1306 agregados
    [Amiplanta.kicad_sch, ESP32.kicad_sch, bootloader.kicad_sch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]
2022-10-06 Agregado circuito de potencia a través de Jack y selector de posición para alimentar de USB, Jack o apagar
    [Amiplanta.kicad_sch, Power.kicad_sch, bootloader.kicad_sch]
2022-10-10 sensores 1
    [APDS-9960.step, Amiplanta.kicad_sch, ESP32.kicad_sch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]
2022-10-11 Conexion Sensores
    [Amiplanta.kicad_sch, sensores.kicad_sch]
2022-10-15 actualizacion huellas resitencias y capacitorees
    [Amiplanta.kicad_sch, ESP32.kicad_sch, Power.kicad_sch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]
2022-10-15 Huellas asignadas. Revisar si algunos de los módulos serán cambiados por conectores Molex.
    [pantallaOled.kicad_sch]
2022-10-20 Desarrollo PCB
    [APDS-9960.step, Amiplanta.kicad_sch, ESP32.kicad_sch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]
2022-10-25 Correciones Finales Esquemático - Revisar error con huella del Amplificador de Sonido
    [APDS-9960.step, ESP32.kicad_sch, Esquematico.kicad_pcb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]
2022-10-25 PCB organizada para autoruteo
    [amiplanta.kicad_pcb, amiplanta.kicad_sch, sensores.kicad_sch]
2022-10-25 PCB Final
    [amiplanta.dsn, amiplanta.kicad_pcb]
2022-10-26 Placa diseño Final para imprimir
    [amiplanta.kicad_pcb]
2022-11-01 Esquematico final y ejemplos riot
    [APDS-9960.step, ESP32.kicad_sch, Power.kicad_sch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]
2022-11-23 Oled Con logo Amiplanta (instrucciones en README sd1306_i2c
    [amiplanta.csv]
2022-12-07 Add files via upload
    Diseño 3D final
    [ensamble v11.stl]
